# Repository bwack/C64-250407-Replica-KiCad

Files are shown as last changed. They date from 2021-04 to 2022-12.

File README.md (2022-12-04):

# The C64 250407 replica

A replica of the Commodore 64 250407 1983 mother board, and the schematics.

The replica project was started by Michael K. (Der Alte Bastler) in 2019 to learn SprintLayout and the process of reverse engineering PCB. I finished it, importet it in KiCad, imported the KU motherboard schematics and modified it to match the 250407 Reb.B schematics.

The board has been prototyped, and tested by me and Langwell Cowan.

We are not the first to reverse engineer this board, but we are the first to share the design files online I think.

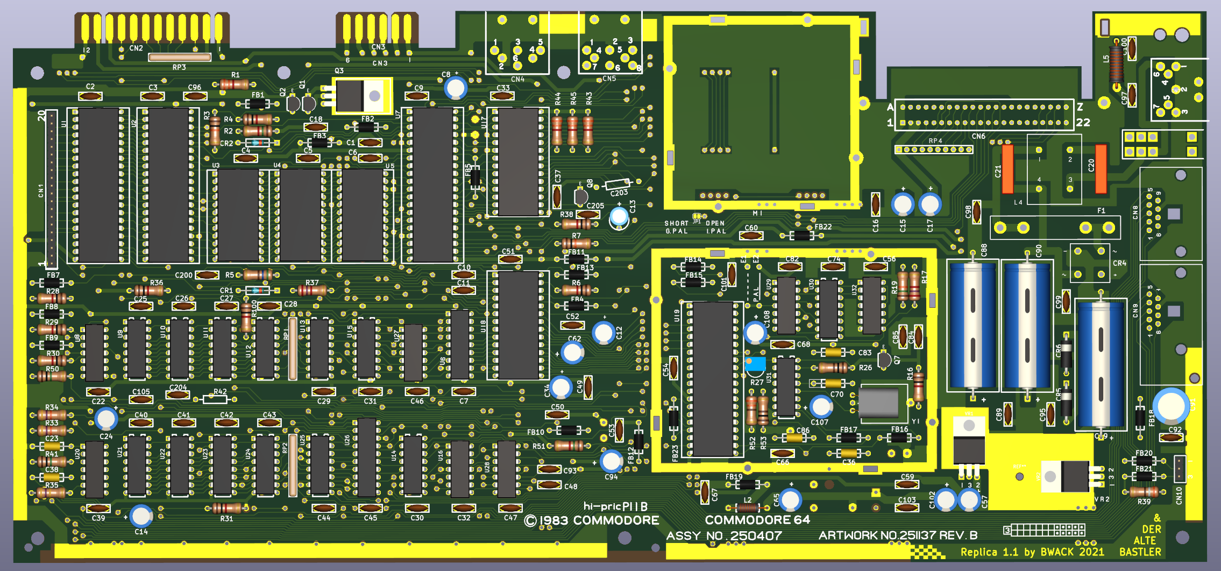
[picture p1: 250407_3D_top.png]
screenshot top

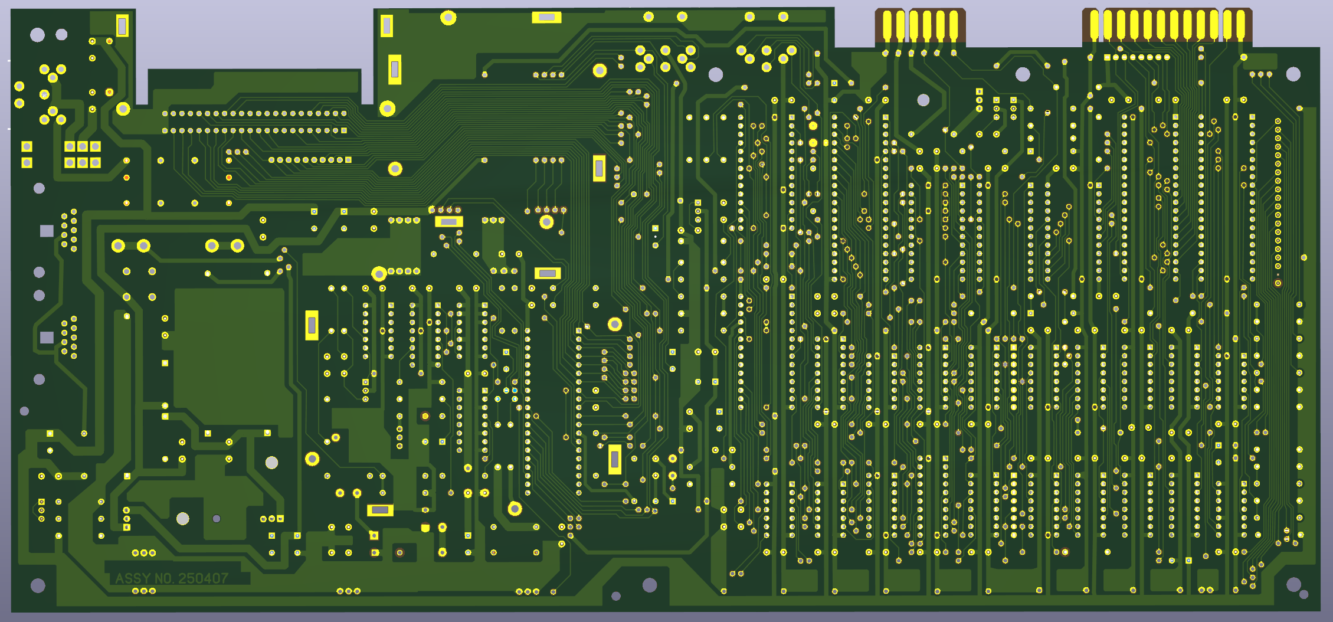
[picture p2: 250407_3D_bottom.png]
screenshot bottom


# BOM

Please see the [BOM file](250407_bom.csv).

Note that some values were left blank because they depend on the clock circuit (PAL/NTSC), and PLA model. They never made it into the schematics. You can find them in a table to the right of the schematics for 250407.
http://www.zimmers.net/anonftp/pub/cbm/schematics/computers/c64/index.html

# Interactive-BOM

[The interactive bom html page](https://htmlpreview.github.io/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) is useful for assembling the board and finding signal traces by using a web browser. Try it here. For a BOM for ordering parts see the BOM above.

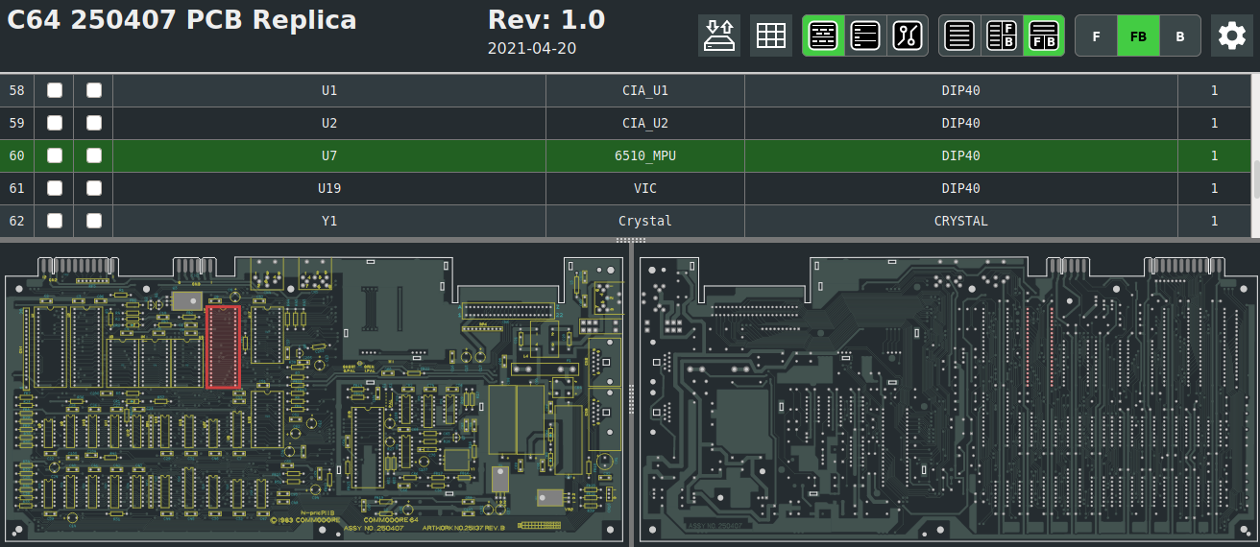
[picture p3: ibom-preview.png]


# Schematics

Download the PDF file [250407_.pdf](250407_.pdf) for a high quality schematics.
Checkout [this tweet](https://twitter.com/paulrickards/status/1371988589974847492) by Paul Rickards where he plots the KU motherboard schematics KU-14194HB :-)

# Change log
- 2022-08-18: Schematics V1.2: symbol and ERC fixes (Pull request from Gabriele Gorla/GGLABS)
- 2020-06-19: PCB and schematics V1.1: First release
- 2020-04-22: PCB and schematics V1.0: Prototype

# YouTube

Part 1-4:

IMAGE ALT TEXT HERE (https://www.youtube.com/watch?v=ox3BLlNSVFU)
IMAGE ALT TEXT HERE (https://www.youtube.com/watch?v=tBIvXRH-Mj0)
IMAGE ALT TEXT HERE (https://www.youtube.com/watch?v=Mg0gVhXbaxc)
IMAGE ALT TEXT HERE (https://www.youtube.com/watch?v=UPUVA1PZOOk)

# License and Disclaimer

Copyright Bwack 2021

This documentation describes Open Hardware and is licensed under the CERN OHL v. 1.2.

You may redistribute and modify this documentation under the terms of theCERN OHL v.1.2. (http://ohwr.org/cernohl). This documentation is distributed WITHOUT ANY EXPRESS OR IMPLIED WARRANTY, INCLUDING OF MERCHANTABILITY, SATISFACTORY QUALITY AND FITNESS FOR APARTICULAR PURPOSE. Please see the CERN OHL v.1.2 for applicable conditions.

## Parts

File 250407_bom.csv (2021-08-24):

Reference | Quantity | Value | Footprint | Mouser P/N | Reichelt P/N | Other
C96 C22 C47 C3 C2 C9 C105 C39 C46 C18 C1 C99 C98 C92 C95 C89 C59 C103 C68 C74 C67 C84 C56 C66 C82 C200 C44 C28 C43 C27 C42 C26 C41 C25 C40 C29 C4 C5 C6 C33 C31 C30 C7 C32 C45 C101 C60 C54 C53 C16 C49 C50 C52 C51 | 54 | .1 | Cap MLCC 0.1uF 50V X7R P5.08mm Radial | 80-C322C104K5R5TA or 581-SR215C104KART | X7R-5 100N
C8 C24 C57 C102 C65 C17 C94 C15 C13 C34 C62 C12 C14 C107 C108 | 15 | 10uF | Cap Alu 10uF 25V 5x5mm P2.5mm Radial | 667-ECE-A1EKS100I | M 10U 25
C11 C10 | 2 | 470pF | Cap MLCC 470pF X7R Axial | 594-A471K15X7RF5UAA | ?
C19 | 1 | 2200uF | Cap Elyt 2200uF 16V 15x30mm Axial | 594-2222-021-16222 or 594-2222-021-15222 or 598-228TTA016M | COS 105 2200/16
C203 | 1 | ? | KU-14194HB-RevB-KiCad:CAPACITOR_RADIAL_P13.97_L9.9_D3.6 | ~
C204 | 1 | ? | KU-14194HB-RevB-KiCad:CAP_P5.08mm | ~
C205 | 1 | 220pF | KU-14194HB-RevB-KiCad:CAP_P5.08mm | ~
C21 C20 | 2 | .22 | Cap Polyester Film 0.22uF 63VAC P10mm | 594-2222-368-25224 | MKS4-100 220N2
C23 | 1 | 360pF | Cap MLCC 350pF 50V C0G Axial | 594-A331J15C0GF5TAA | ?
C36 | 1 | 20pF | Cap MLCC 20pF C0G Axial | 581-SA102A200JAR | ?
C37 | 1 | 1000pF | KU-14194HB-RevB-KiCad:CAP_P5.08mm | ~
C38 | 1 | 51pF | Cap MLCC 51pF (47pF OK) X7R Axial | 581-SA102A470JAR | ?
C48 C93 | 2 | 1800pF | Cap MLCC 1800pF X7R Axial | 581-SA101C182KAR | ?
C70 | 1 | 15pF 5% | Cap MLCC 15pF 50V 5% C0G Axial/Radial Leaded | 594-A150J15C0GH5TAA | KERKO 15P
C85 | 1 | .47 | Cap MLCC 0.47uF +80/-20% X7R P5.08mm Radial | 80-C330C474K5R or 81-RCER71H474K1K1H3B | Z5U-5 470N
C86 C83 | 2 | 82pF | Cap MLCC 82pF 100V C0G Axial / Radial Disc | 80-C410C820J1G
C88 | 1 | 1000uF | Cap Elyt 1000uF 16V 20% 10x30mm Axial | 594-2222-021-15102 or 598-108TTA016M
C90 | 1 | 470uF | Cap Elyt 470uF 50V 20% 13x26mm Axial | 598-477TTA050M | COS 105 470/50
C91 | 1 | 100uF | Cap Elyt 100uF 16V 20% 6.3x11mm Radial | REA101M1CBK-0611P | FR-A 100U 16
C97 C100 | 2 | .22 | Cap MLCC 0.22uF 50V X7R P5.08mm Radial | 80-C330C224K1R | Z5U-5 220N
CN1 | 1 | KEYBOARD_20PIN_MALE | Pin Header 20 POS P2.54mm male vertical | 538-22-28-4204 | MPE 087-1-020
CN10 | 1 | LED_CONNECTOR | Pin Header 3 POS P2.54mm male vertical | 538-22-28-4033 | RND 205-00624
CN2 | 1 | USER_PORT_CON | KU-14194HB-RevB-KiCad:EDGE_CON_24P | -
CN3 | 1 | CASSETTE_PORT_CON | KU-14194HB-RevB-KiCad:EDGE_CON_12P_TAPE | -
CN4 | 1 | SERIAL_BUS_CON | KU-14194HB-RevB-KiCad:SERIAL_CON_DIN6
CN5 | 1 | AV_CONN | KU-14194HB-RevB-KiCad:AV_CON_DIN8 | -
CN6 | 1 | EXPANSION_PORT | Conn Edge Dual Female 44 POS P2.54mm |  | Digikey: H122591-ND
CN7 | 1 | POWER_CON | KU-14194HB-RevB-KiCad:POWER_CON_D7_250407
CN8 CN9 | 2 | CONTROL_PORT | Standard Connector DSUB E09P RA590 | 571-5747467-1
CR1 | 1 | IN4371 | Zener Diode 2.7V 500mW DO-35-2 | 78-TZX2V7A | ZF 2,7
CR100 CR102 CR101 CR103 | 4 | D_Small_ALT |  | ~
CR2 | 1 | IN755 | Zener Diode 7.5V 500mW DO-35-2 | 78-TZX7V5C | ZF 7,5
CR4 | 1 | BRIDGE_RECTIFIER | Bridge Rectifier 2A 600V Vf=1.05V | 627-S2VB60-5000 | KBPC604 DIO
CR5 CR6 | 2 | 1N4001 | Rectifier 1A Vr=50V | 625-1N4001-E3/54 or 625-1N4001-E3/53
E1 | 1 | JUMPER_WIRE | KU-14194HB-RevB-KiCad:JUMPER_WIRE | -
E2 | 1 | JUMPER_WIRE_DASHED | KU-14194HB-RevB-KiCad:JUMPER_WIRE | -
F1 | 2 | 1A | Fuse Clips (buy two) | 504-BK/1A1907-03-R
FB18 FB4 FB22 FB12 FB14 FB15 FB13 FB10 FB11 | 9 | FERRITE_BEAD | Ferrite Bead D3.5 L4.45mm Axial | 623-2743001112LF or 81-BL01RN1A2A2B | BEAD 8-21
FB7 FB9 FB8 FB5 FB2 FB1 FB3 FB20 FB21 FB17 FB16 FB19 FB23 | 13 | FERRITE_NARROW | Ferrite Bead D3.5 L4.45mm Axial | 623-2743001112LF or 81-BL01RN1A2A2B | BEAD 8-21
JP1 | 1 | Jumper_NC_Small | Jumper:SolderJumper-2_P1.3mm_Bridged_RoundedPad1.0x1.5mm | ~
L2 | 1 | 2.2uH | Inductor 2.2uH 5% Radial | 652-78F2R2J-RC | L-MICC 2,2µ
L4 | 1 | CHOKE | Common Mode Choke 250V 3.8mH 2.1A 150mOhms | 80-SSR10V-21038
L5 | 1 | 1.2uH | Inductor 1.5uH 10% Radial | 542-5800-4R7-RC | L-HBCC 1,5µ
M1 | 1 | MODULATOR_LONGBOARD | KU-14194HB-RevB-KiCad:MODULATOR_PORT_LONGBOARD | -
Q2 Q1 Q7 Q8 | 4 | 2SC1815 | Bipolar Transistor TO-92 Vce=60V 400mA | 2SC1815 | SC 1815
Q3 | 1 | TP29B/2SD880 | Bipolar Transistor TO-220 | 512-KSD880YTU | SD 880
R1 R43 R44 R45 | 4 | 3K3 | Resistor 3K3 0207 Axial | 594-MBB02070C3301FC1 | METALL 3,30K
R17 R37 | 2 | 2K7 | Resistor 2K7 0207 Axial | 594-MBB02070C2701FCT | METALL 2,70K
R19 | 1 | 15K | Resistor 15K 0207 Axial | 594-MBB02070C1502FC1 | METALL 15,0K
R2 R51 | 2 | 1.5K | Resistor 1K5 0207 Axial | 594-MBB02070C1501FCT | 1W 1,5K
R26 R53 | 2 | 100 | Resistor 100 0207 Axial | 594-MBB02070C1000FCT | METALL 100
R27 | 1 | 500 | Trimmer Resistor 500 Ohms Linear | 652-3306F-1-501 | BOU 3386P-1-501
R28 R30 R29 R36 R4 R16 R100 R31 R38 R6 | 10 | 1K | Resistor 1K 0207 Axial | 594-MBB02070C1001FCT | METALL 1,00K
R3 R7 | 2 | 10K | Resistor 10K 0207 Axial | 594-MBB02070C1002FCT | METALL 10,0K
R33 R34 | 2 | 47K | Resistor 47K 0207 Axial | 594-MBB02070C4702FC1 | METALL 47,0K
R35 | 1 | 470K | Resistor 470K 0207 Axial | 594-MBB02070C4703FCT | METALL 470K
R39 | 1 | 390 | Resistor 390 0207 Axial | 594-MBB02070C3900FCT | METALL 390
R41 R50 | 2 | 1M | Resistor 1M 0207 Axial | 594-MBB02070C1004FCT or 603-HHV-25JT-52-1M
R42 | 1 | ~ | KU-14194HB-RevB-KiCad:RESISTOR | - | -
R5 | 1 | 560 | Resistor 560 0207 Axial | 594-MBB02070C5600FCT | METALL 560
R52 | 1 | 330 | Resistor 330 0207 Axial | 594-MBB02070C3300FCT
RP1 RP2 | 2 | 33 | Resistor Network 33R Isolated 8 pin SIP | 652-4308R-2LF-33 or 268-33-RC
RP3 | 1 | R_ARRAY_7WAY_US | Resistor Network 3K3 Bussed 8 pin SIP | 774-77081332P
RP4 | 1 | R_ARRAY_9WAY_US | Resistor Network 3K3 Bussed 10 pin SIP | 774-770101332P
SW1 | 1 | POWER_SWITCH | KU-14194HB-RevB-KiCad:POWER_SWITCH
U1 | 1 | CIA_U1 | KU-14194HB-RevB-KiCad:DIP40 | -
U12 U24 U11 U23 U10 U22 U21 U9 | 8 | 4164-2 | KU-14194HB-RevB-KiCad:DIP16 | -
U14 | 1 | 74LS258 | QUADRUPLE 2-LINE TO 1-LINE DATA SELECTORS/MULTIPLEXERS | 595-SN74LS258BN
U15 | 1 | 74LS139 | DUAL 2-LINE TO 4-LINE DECODERS/MULTIPLEXERS | 595-SN74LS139AN
U17 | 1 | PLA_U17 | KU-14194HB-RevB-KiCad:DIP28 | -
U18 | 1 | 6581 | KU-14194HB-RevB-KiCad:DIP28 | -
U19 | 1 | VIC | KU-14194HB-RevB-KiCad:DIP40 | -
U2 | 1 | CIA_U2 | KU-14194HB-RevB-KiCad:DIP40 | -
U20 | 1 | 556 | DUAL PRECISION TIMERS | 595-NE556N
U25 U13 | 2 | 74LS257 | QUADRUPLE 2-LINE TO 1-LINE DATA SELECTORS/MULTIPLEXERS | 595-SN74LS257BN
U26 | 1 | 74LS373 | OCTAL D-TYPE TRANSPARENT LATCHES AND EDGE-TRIGGERED FLIP-FLOPS | 595-SN74LS373N
U27 | 1 | 7408 | QUADRUPLE 2-INPUT POSITIVE-AND GATES | 595-SN74LS08N
U28 U16 | 2 | 4066 | CMOS Quad Bilateral Switch | 595-CD4066BE
U29 | 1 | 74LS74 | DUAL D-TYPE POSITIVE-EDGE-TRIGGERED FLIP-FLOPS WITH PRESET AND CLEAR | 595-SN74LS74AN
U3 U4 | 2 | 2364A | KU-14194HB-RevB-KiCad:DIP24 BASIC AND KERNAL ROM | -
U30 | 1 | 74LS193 | SYNCHRONOUS 4-BIT UP/DOWN COUNTERS (DUAL CLOCK WITH CLEAR) | 595-SN74LS193N
U31 | 1 | 74LS629N | VOLTAGE-CONTROLLED OSCILLATORS | 595-SN74LS629N
U32 | 1 | MC4044 | KU-14194HB-RevB-KiCad:DIP14 | -
U5 | 1 | 2332A | KU-14194HB-RevB-KiCad:DIP24 CHAR ROM | -
U6 | 1 | 2114 | KU-14194HB-RevB-KiCad:DIP18 COLOR RAM | -
U7 | 1 | 6510_MPU | KU-14194HB-RevB-KiCad:DIP40 | -
U8 | 1 | 7406N | HEX INVERTER BUFFERS/DRIVERSWITH OPEN-COLLECTOR HIGH-VOLTAGE OUTPUTS | 595-SN7406N
VR1 | 1 | 7812 | Linear Voltage Regulators 12V 1A Positive | 863-MC7812CTG
VR2 | 1 | 7805 | Linear Voltage Regulators 5V 1A Positive | 863-MC7805CTG
Y1 | 1 | Crystal | Crystals HC49/U | 815-AB-17.734475-B4
Other:
 | Quantity |  | Description | mouser
 | 4 |  | Socket PDIP 40P P2.54mm W15.24mm DUAL WIPE | 517-4840-6000-CP
 | 2 |  | Socket PDIP 28P P2.54mm W15.24mm DUAL WIPE | 517-4828-6000-CP
 | 3 |  | Socket PDIP 24P P2.54mm W15.24mm DUAL WIPE | 517-4824-6000-CP
 | 1 |  | Socket PDIP 20P P2.54mm W7.62mm DUAL WIPE | 517-4820-3000-CP
 | 1 |  | Socket PDIP 18P P2.54mm W7.62mm DUAL WIPE | 517-4818-3000-CP
 | 14 |  | Socket PDIP 16P P2.54mm W7.62mm DUAL WIPE | 517-4816-3000-CP
 | 7 |  | Socket PDIP 14P P2.54mm W7.62mm DUAL WIPE | 517-4814-3000-CP

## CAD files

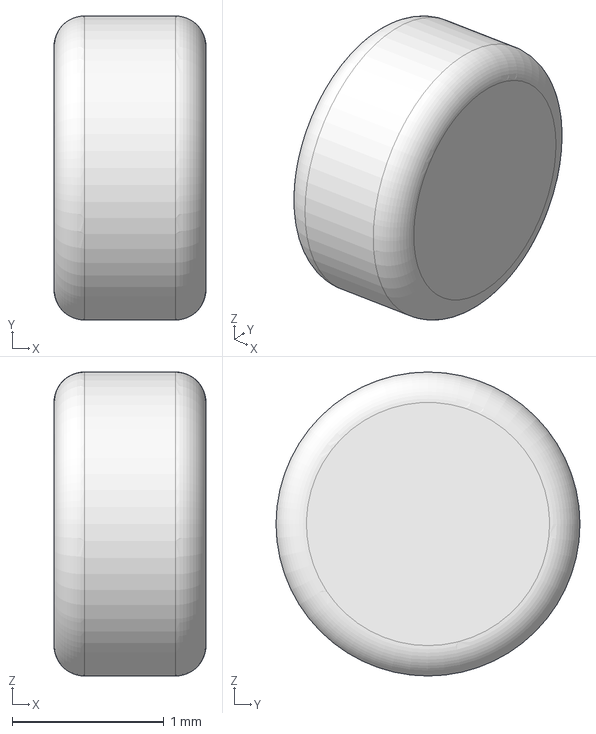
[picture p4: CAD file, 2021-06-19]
3D-models/unitary_ring.fcstd
1.00 x 2.00 x 2.00 mm

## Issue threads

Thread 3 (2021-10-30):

Q7 on the interactive BOM should be c945

TheSupremeMonkey, 2021-10-30:
I love the project and have been watching it on YouTube just waiting for the open release. Just finished my first board and I only ran into one issue. The interactive BOM lists a C1815 for the Q7 transistor for the video circuit. When I used one I got garbage video output.  I could just barely tell that basic was up but the static was so bad it was unusable. I have a bunch of 250407 boards and when I checked my stock boards they all had a C945 with the higher maximum frequency. When I swapped a C945 in for the C1815 everything worked great and the picture was perfect.

TheSupremeMonkey, 2021-10-31:
The more I think about it and look at the schematics I'm starting to think maybe I just had a bad transistor. When I get a chance I may test a few different transistors to see if it was just a bad component.

TheSupremeMonkey, 2021-10-31:
Looks like it was just a bad transistor. Sorry for the false alarm.

Closed 2021-10-31.

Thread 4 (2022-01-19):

Should R31 be 1K or 180R ?

DusteDdk, 2022-01-19:
Thank you for the awesome interactive BOM, it's an great tool!
In the IBOM R31 is listed as 1K but I think it should be 180 Ohm,
Is this a difference between NTSC and PAL ?

bwack, 2022-02-08:
Hi. I confirmed that R31 is 1K in the Schematics PDF and ibom.
I remember this being 180 in the original schematics for the longboards.
1. I've seen 1K used on the PCB boards
2. 180 Ohms would stress the 7406, wouldn't have enough output drive to drag the voltage down.

DusteDdk, 2022-02-09:
Yes now I understand, it's simply a pullup, 180 ohm worked fine on my byard, but I it's a balance between noise and power usage, I changed mine to 1k as well, it still seems to work just fine, thanks for saving our 7406's ;)

Closed 2022-02-09.

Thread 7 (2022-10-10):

Testing the rails

SR-dude, 2022-10-10:
I think I’ll take the plunge.  Is the breadboard sold at pcbway the better one?

More seriously, I’ve seen some videos where people just put the board together without testing as they go. No checking their work. I don’t want to take that approach. What I want to do is use a bench power supply and test the traces on the board, even before installing the 12 & 5 V regulators.  Where on your board where the voltages should be tapped?

bwack, 2022-10-11:
Check the schematic and the interactive bom. It's all there.

bwack, 2022-10-11:
I don't understand the breadboard question.

bwack, 2022-10-11:
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
You'll find the interactive BOM in the readme page.

SR-dude, 2022-10-11:
Thanks.  I’ll get the the board from pcbway sponsored by you.

bwack, 2022-10-11:
Only the video was sponsored , but cool that you get this board anyway 🙂

Closed 2022-10-11.

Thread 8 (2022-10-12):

Beveling?

SR-dude, 2022-10-12:
When placing the order for your shared project at pcbway, I was asked a question.  “You(me) chose “beveling” online but noted “not beveling “.  I checked and the default choice is “Yes at 30 degrees”. I don’t know how beveling could have been turned off. Did the gerbers do it?. What do you recommend?

bwack, 2022-10-12:
Bevelling, as in making the pcb edge connectors chamfered at an angle is not possible to choose in gerber i think, therefore they ask.

Though they will probably get back to you and say that they can't do it because the pcb edge connectors are not far enough out on the edge. They told me otherwise the whole upper edge of the pcb would be bevelled. I guess they don't have a tool that can do only the connector, just the full edge if you know what mean.

SR-dude, 2022-10-12:
I suppose I should leave beveling off then.

Closed 2022-12-02.

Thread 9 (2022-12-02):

Orientation of the L4 choke

SR-dude, 2022-12-02:
I have a indented corner and on the opposite corner it reads "BL".  There are two orientations to fit this in L4. The indent is either pin 2 or pin 4. Do you know which?

bwack, 2022-12-04:
I don't know your part, and BL I don't know. So you are asking if it is possible to mount is backwards ? It would work, as long as you don't mount it "side ways", then it would short the power supply.
Looking at the common mode chokes, the look very symmetrical though, so I wouldn't worry about the orientation other than having it pass current rather than shorting it. If it's an open design, you can see where the wires go, if not you can use a multimeter to find what pins are joined (measure a low resistance). I hope this helps.

SR-dude, 2022-12-04:
I got it from a retro shop that  sells a c64 parts kit.  I think its a Kemet  SU10VD-10010. In any case, looking at it, it looks like that it is symmetrical. It's not square. So, there is only two ways to fit. Either will do.

Closed 2022-12-04.

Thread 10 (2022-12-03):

C203

SR-dude, 2022-12-03:
What do you suggest I do about C203? It has no value and footprint in the BOM:
KU-14194HB-RevB-KiCad:CAPACITOR_RADIAL_P13.97_L9.9_D3.6

The interactive BOM calls it a 82pF Radial Capacitor. But, it doesn't appear to be
 connected. You videos on youtube just skip it.

It might help me better to understand what "P13.97_L9.9_D3.6" means.

bwack, 2022-12-04:
If you look up the original schematics for the 250407, C203 is mentioned in a table to the right.
http://www.zimmers.net/anonftp/pub/cbm/schematics/computers/c64/251138-1of2-right.gif

The name of the footprint is just an identifier for the footprint, not the part. P L D stands for Pitch length diameter. I think, it's been a while.

SR-dude, 2022-12-04:
Okay, from what I read about c203, it is never populated.

Closed 2022-12-04.

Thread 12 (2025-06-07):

250407 E1/E2/E3 PAL/NTSC corrections

fredsa, 2025-06-07:
Here's my board:
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

Here are two places where corrections are needed:

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

bwack, 2025-06-07:
Thanks, Fred! I see an error on the silkscreen. What is the second error?

bwack, 2025-06-09:
Done. Thanks !

Closed 2025-06-09.

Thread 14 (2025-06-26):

Bar above inverted signals renders poorly in PDF

fredsa, 2025-06-26:
In a recent update (thank you for the https://github.com/bwack/C64-250407-Replica-KiCad/pull/13 fixes!), the rendering of the PDF changed, making it more difficult to clearly make out the bar above inverted signals.

Compare:

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

- Does KiCAD 9.0.1 maybe render differently?
- Are there KiCAD or 'print to PDF' settings that could be changed to make the output better?

bwack, 2025-06-29:
I checked. Yes it renders differently, and no there are no export functions for this. Unfortunately.

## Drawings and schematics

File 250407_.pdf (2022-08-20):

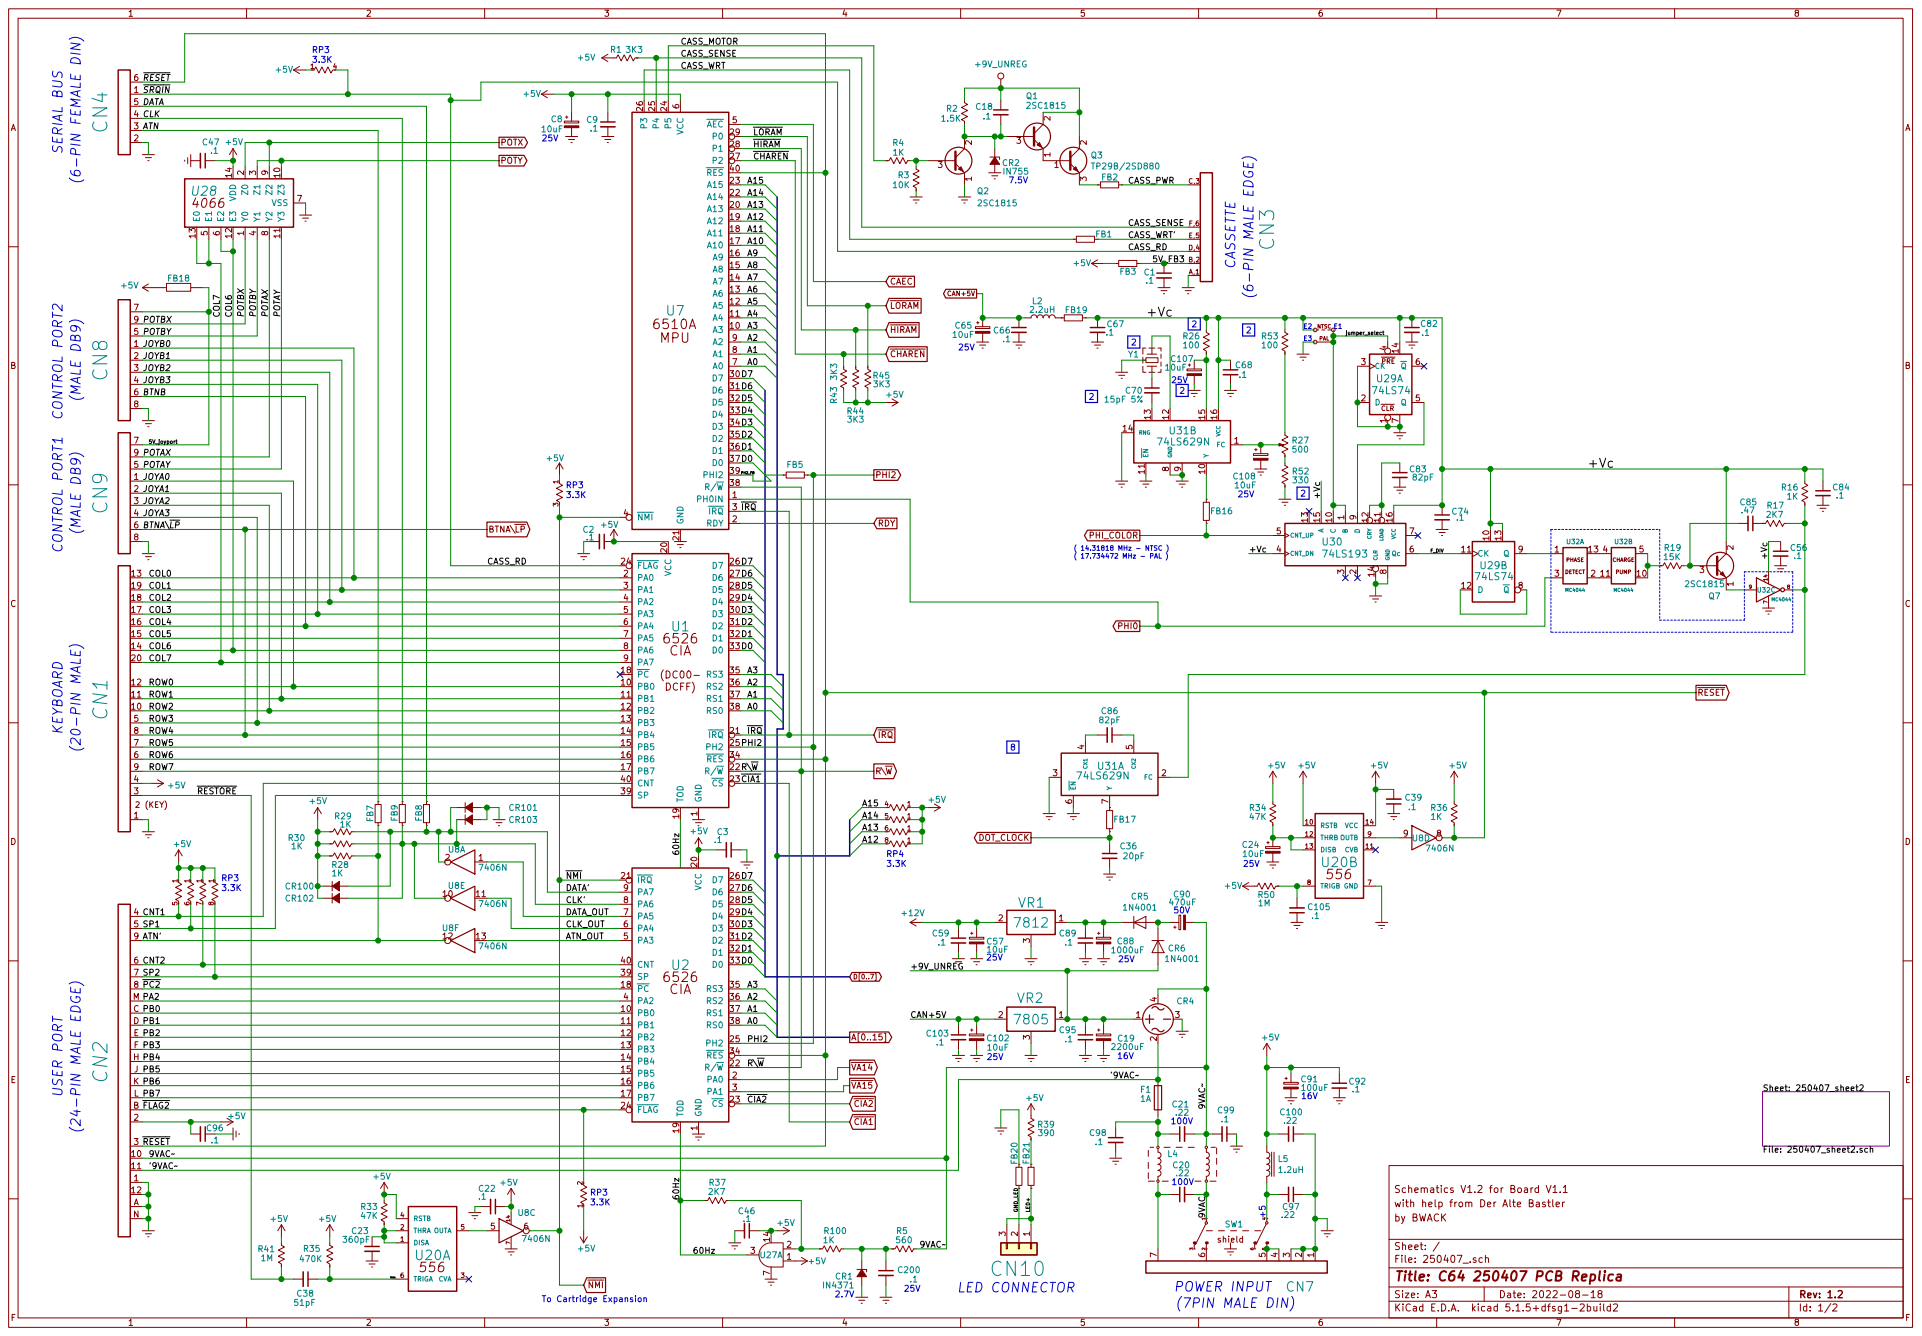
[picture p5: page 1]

To Cartridge Expansion (MALE DB9) CONTROL PORT2

3 JOYB2

2 JOYA1
4 JOYA3

IRQ

19
18
17
16
15

(7PIN MALE DIN) KEYBOARD (20-PIN MALE)

12
11
10
ROW7 | R\W
4 | CIA1

7 SP2

'9VAC

11 '9VAC

File: 250407_.sch Sheet: / by BWACK

Id: 1/2 Title: C64 250407 PCB Replica

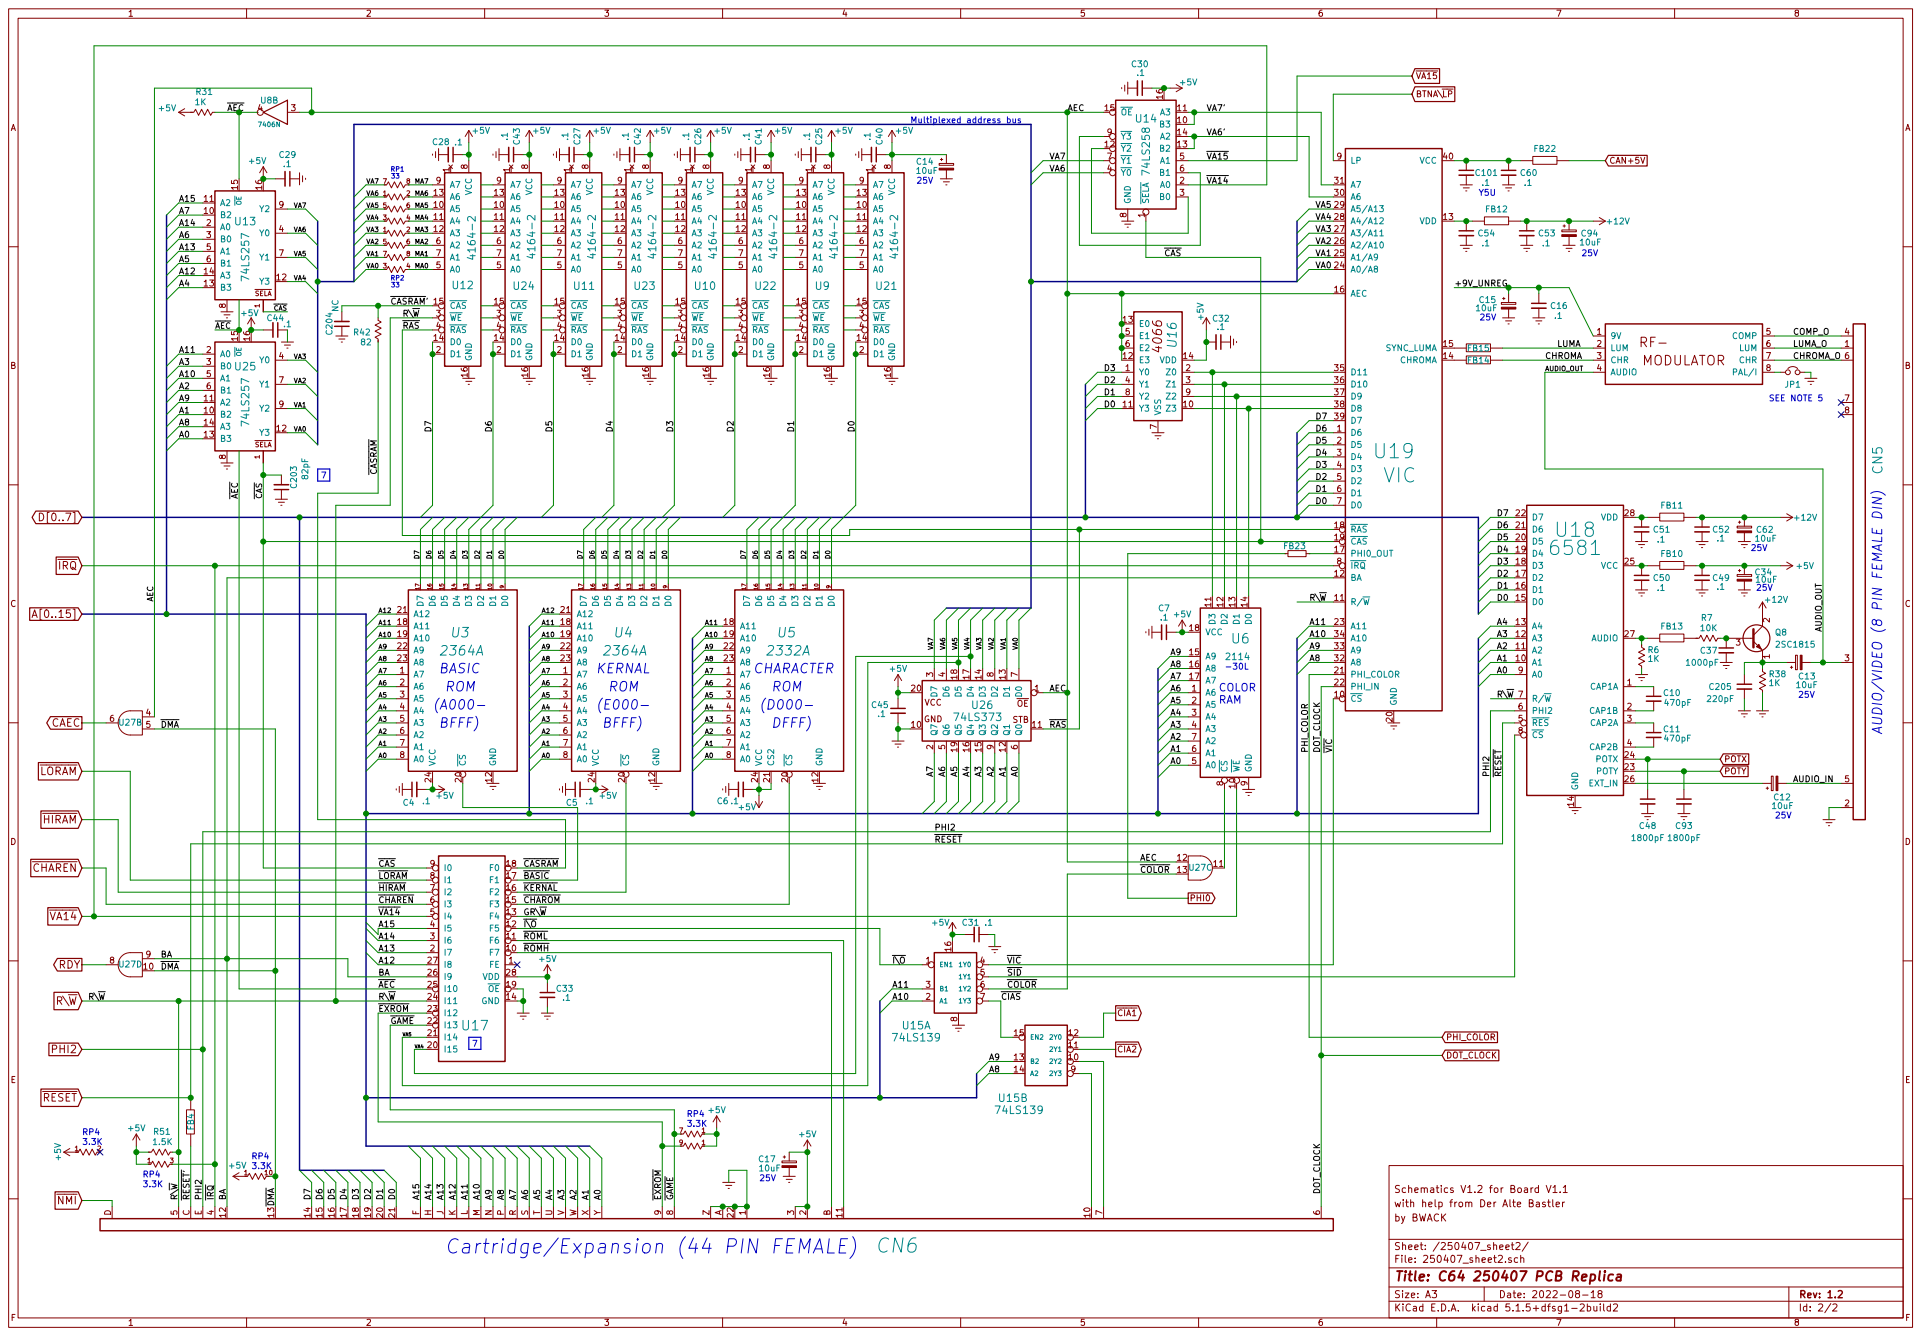
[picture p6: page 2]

1 A5 10 A4 11 A3 12 A6 13 D0 14 CAS 15 GND 16 D1 2 WE 3 RAS 4 A0 5 A2 6 A1 7 VCC

with help from Der Alte Bastler Schematics V1.2 for Board V1.1

Sheet: /250407_sheet2/
File: 250407_sheet2.sch
Id: 2/2 Title: C64 250407 PCB Replica

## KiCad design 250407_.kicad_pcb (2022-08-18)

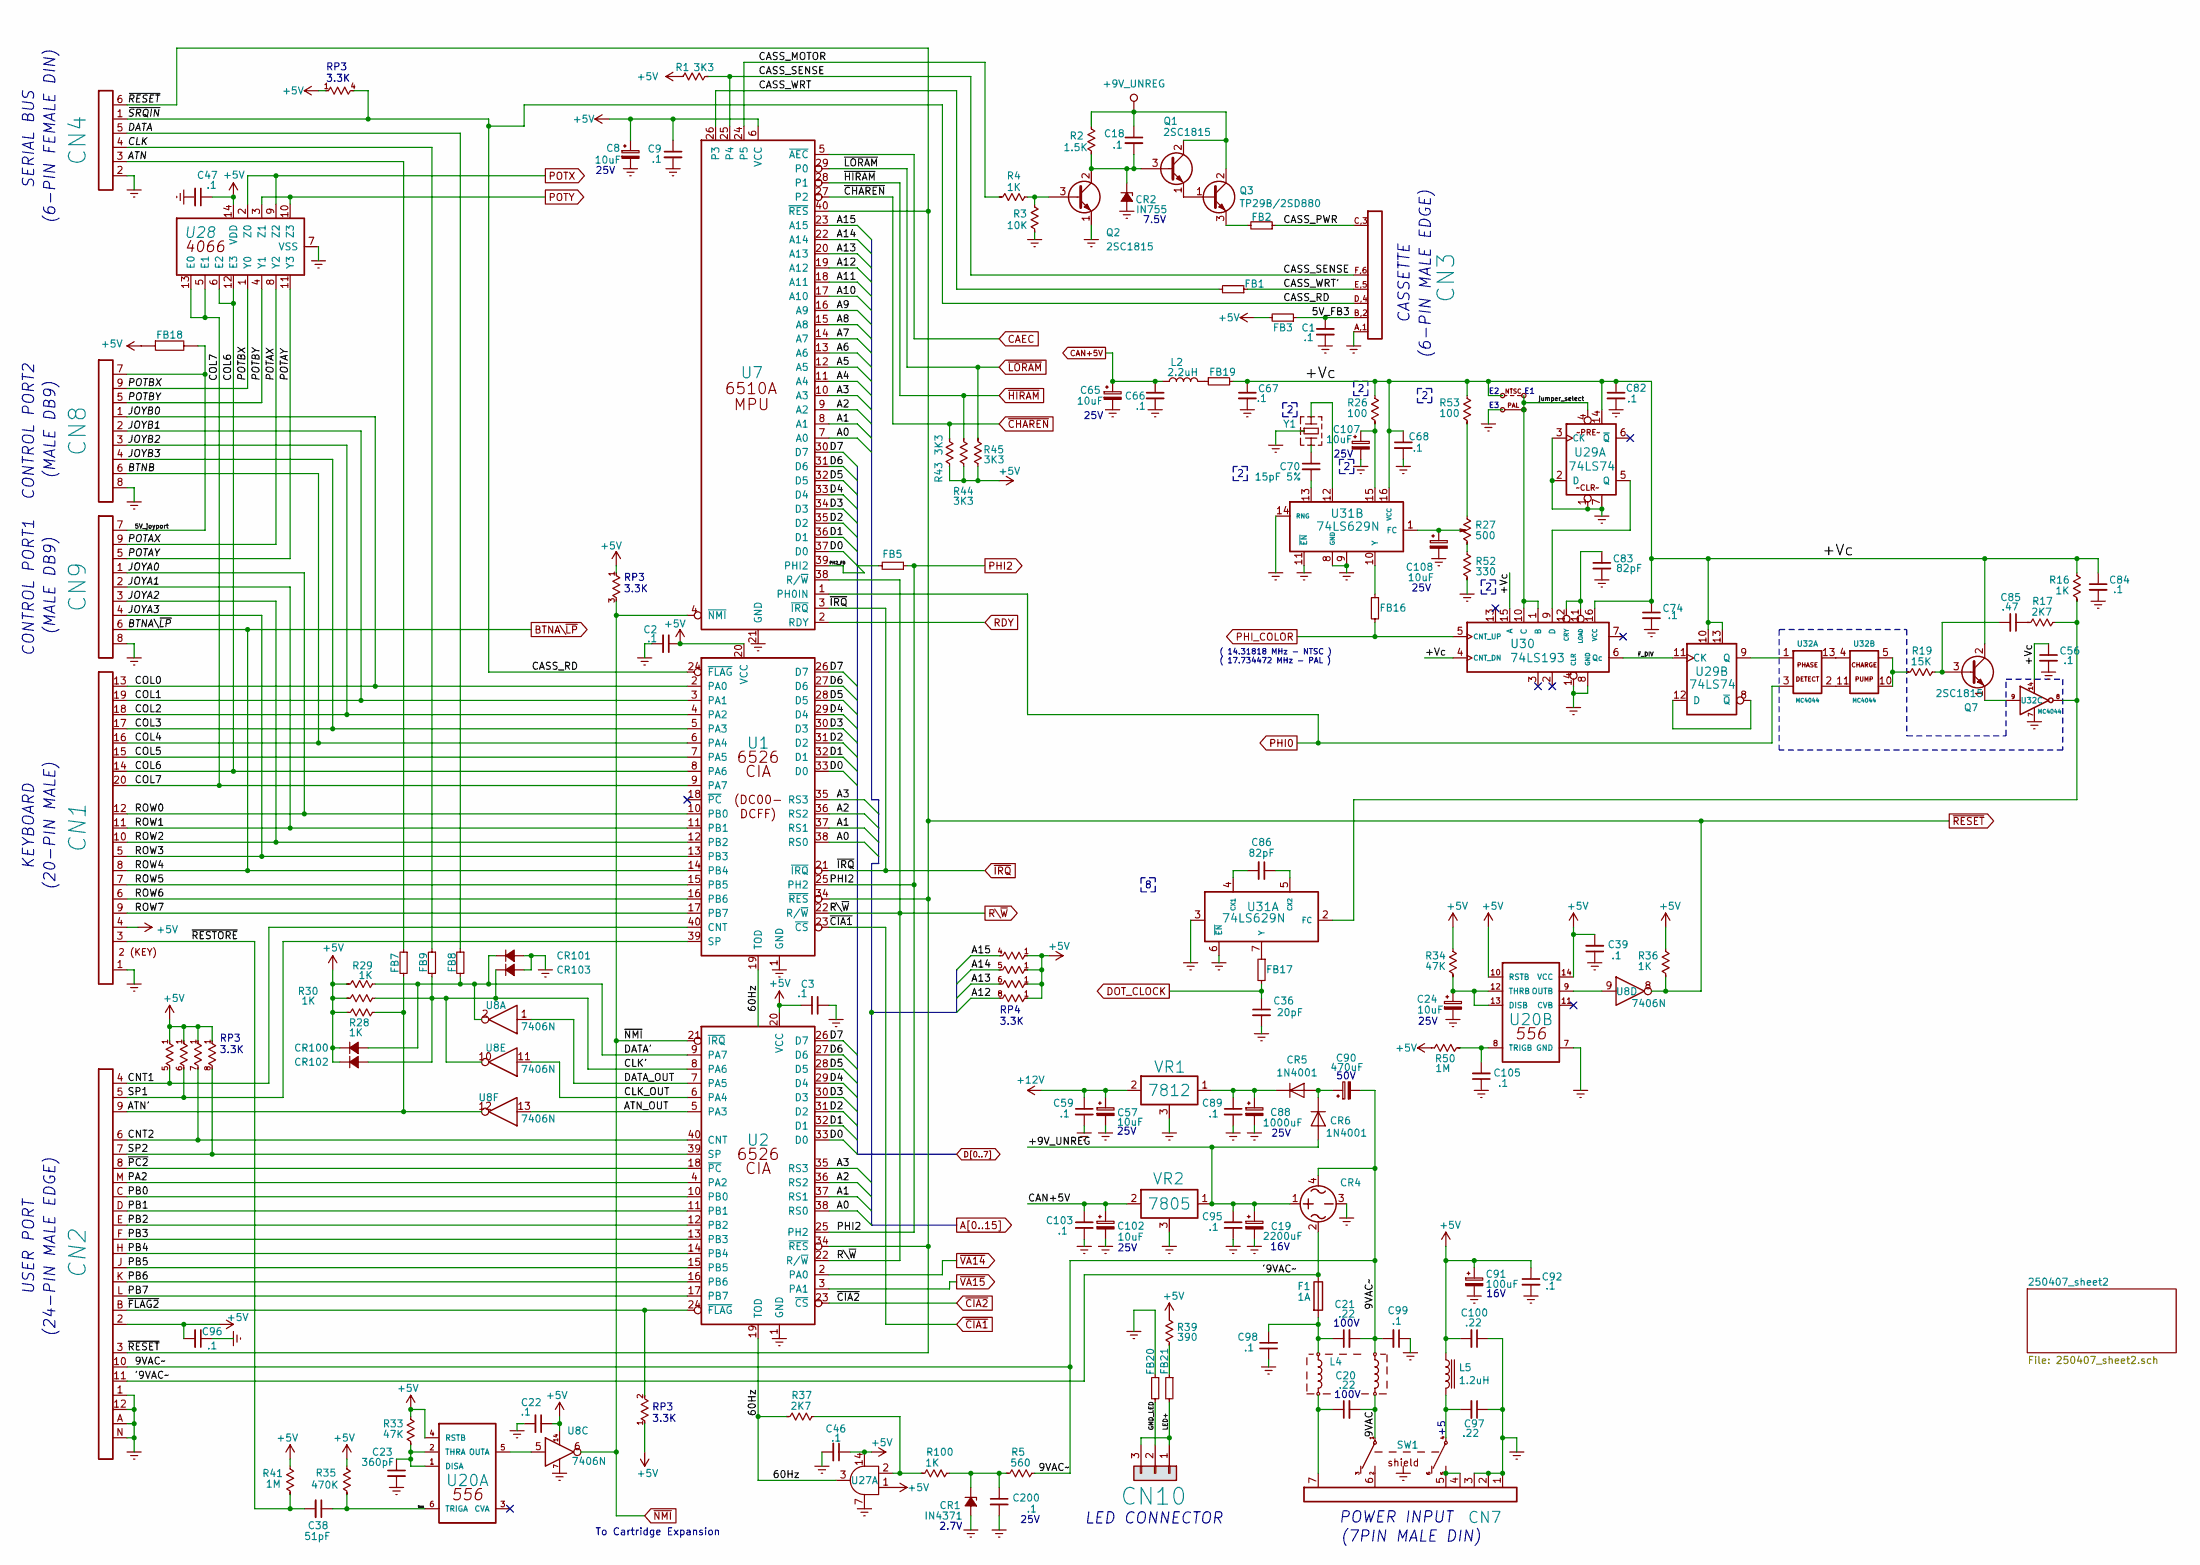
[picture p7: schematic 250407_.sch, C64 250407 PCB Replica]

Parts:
C1, C2, C3, C9, C18, C22, C39, C46, C47, C56, C59, C66, C67, C68, C74, C82, C84, C89, C92, C95, C96, C98, C99, C103, C105, C200: .1; CAP_P5.08mm
C8, C24, C57, C65, C102, C107, C108: 10uF; CAP_ELYT_RADIAL_P5.08mm_SMALL_RING
C19: 2200uF; LARGE_ELECTROLYTIC_AXIAL_TH
C20, C21: .22; CAP_POLY_100V_TH_P5.08_and_P12.07mm
C23: 360pF; CAP_AXIAL_P12.7mm
C36: 20pF; RESISTOR
C38: 51pF; CAP_AXIAL_P12.7mm
C70: 15pF 5%; RESISTOR
C83, C86: 82pF; RESISTOR
C85: .47; CAP_P5.08mm
C88: 1000uF; LARGE_ELECTROLYTIC_AXIAL_TH
C90: 470uF; LARGE_ELECTROLYTIC_AXIAL_TH
C91: 100uF; CAP_ELYT_RADIAL_P5.08mm
C97, C100: .22; CAP_P5.08mm
CN1: KEYBOARD_20PIN_MALE; KEYBOARD_CON
CN2: USER_PORT_CON; EDGE_CON_24P
CN3: CASSETTE_PORT_CON; EDGE_CON_12P_TAPE
CN4: SERIAL_BUS_CON; SERIAL_CON_DIN6
CN7: POWER_CON; POWER_CON_D7_250407
CN8, CN9: CONTROL_PORT; JOYPORT_DB9
CN10: LED_CONNECTOR; LED_CON
CR1: IN4371; ZENER_12.7mm
CR2: IN755; ZENER_12.7mm
CR4: BRIDGE_RECTIFIER
CR5, CR6: 1N4001; RECTIFIER_TH_P12.7mm
CR100, CR101, CR102, CR103: D_Small_ALT
E1: JUMPER_WIRE
E2: JUMPER_WIRE_DASHED; JUMPER_WIRE
F1: 1A; FUSE
FB1, FB2, FB3, FB5, FB7, FB8, FB9, FB16, FB17, FB18, FB19, FB20, FB21: FERRITE_BEAD; FERRITE_BEAD_TH_P12.7mm
L2: 2.2uH; RESISTOR
L4: CHOKE
L5: 1.2uH; INDUCTOR_P15.24mm
Q1, Q2, Q7: 2SC1815; Q_NPN_ECB
Q3: TP29B/2SD880; TO-220-3_Horizontal_TabDown_250407
R1, R43, R44, R45: 3K3; RESISTOR
R2: 1.5K; RESISTOR
R3: 10K; RESISTOR
R4, R16, R28, R29, R30, R36, R100: 1K; RESISTOR
R5: 560; RESISTOR
R17, R37: 2K7; RESISTOR
R19: 15K; RESISTOR
R26, R53: 100; RESISTOR
R27: 500; POTMETER
R33, R34: 47K; RESISTOR
R35: 470K; RESISTOR
R39: 390; RESISTOR
R41, R50: 1M; RESISTOR
R52: 330; RESISTOR
RP3: 3K3 Bussed; RP_ARRAY_7WAY
RP4: 3K3 Bussed; RP_ARRAY_9WAY
SW1: POWER_SWITCH
U1: CIA_U1; DIP40
U2: CIA_U2; DIP40
U7: 6510_MPU; DIP40
U8: 7406N; DIP14
U20: 556; DIP14
U27: 7408_U27; DIP14
U28: 4066_U28; DIP14
U29: 74LS74; DIP14
U30: 74LS193; DIP16
U31: 74LS629N; DIP16
U32: MC4044; DIP14
VR1: 7812; VREG_TO-220-3_Horizontal_TabDown
VR2: 7805; VREG_TO-220-3_Horizontal_TabDown
Y1: Crystal; CRYSTAL

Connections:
+5V: C2.1, C3.2, C8.1, C9.1, C22.1, C39.2, C46.1, C47.1, C91.1, C92.1, C96.2, C100.2, CN1.4, CN2.2, CR100.1 (K), CR102.1 (K), FB3.2, FB18.1, L5.1, R1.1, R28.2, R29.2, R30.2, R33.1, R34.1, R35.1, R36.1, R39.1, R41.1, R43.1, R44.1, R45.1, R50.1, RP3.1, RP4.1, U1.20 (VCC), U2.20 (VCC), U7.6 (VCC), U8.14, U20.4 (RSTB), U20.10 (RSTB), U20.14 (VCC), U27.1, U27.14, U28.14 (VDD); also elsewhere on the board
+9V_UNREG: C18.1, C19.1, C95.1, CR4.1, CR6.2 (A), Q1.2 (C), Q3.2 (C), R2.1, VR2.1; also elsewhere on the board
+12V: C57.1, C59.1, VR1.2; also elsewhere on the board
/5V_FB3: C1.1, CN3.B,2, FB3.1
/5V_joyport: CN8.7, CN9.7, FB18.2
/9VAC: C20.2, L4.3, SW1.1
/9VAC~~: C21.2, C90.2, C99.2, CN2.10, CR4.4, L4.4, R5.1
/60Hz: R37.2, U1.19 (TOD), U2.19 (TOD), U27.3
/'9VAC~~: CN2.11, CR4.2, F1.1
/+Vc: C56.1, C67.1, C68.1, C74.1, C82.1, C84.1, E2.1, FB19.2, Q7.2 (C), R16.1, R26.1, R53.1, U29.10, U29.13, U29.14, U30.4 (CNT_DN), U30.15 (A), U30.16 (VCC), U31.16 (VCC), U32.14
/ATN: CN4.3, FB7.1
/ATN': CN2.9, FB7.2, R28.1, U8.12
/ATN_OUT: U2.5 (PA3), U8.13
/BTNB: CN1.16, CN8.6, U1.6 (PA4)
/CASS_MOTOR: R4.2, U7.24 (P5)
/CASS_PWR: CN3.C,3, FB2.1
/CASS_RD: CN3.D,4, CN4.1, RP3.4, U1.24 (~FLAG~)
/CASS_SENSE: CN3.F,6, R1.2, U7.25 (P4)
/CASS_WRT: FB1.2, U7.26 (P3)
/CASS_WRT': CN3.E,5, FB1.1
/CLK: CN4.4, FB9.1
/CLK': CR102.2 (A), CR103.1 (K), FB9.2, R30.1, U2.8 (PA6), U8.10
/CLK_OUT: U2.6 (PA4), U8.11
/CNT1: CN2.4, RP3.5, U1.40 (CNT)
/CNT2: CN2.6, RP3.7, U2.40 (CNT)
/COL0: CN1.13, CN8.1, U1.2 (PA0)
/COL1: CN1.19, CN8.2, U1.3 (PA1)
/COL2: CN1.18, CN8.3, U1.4 (PA2)
/COL3: CN1.17, CN8.4, U1.5 (PA3)
/COL5: CN1.15, U1.7 (PA5)
/COL6: CN1.14, U1.8 (PA6), U28.6 (E2), U28.12 (E3)
/COL7: CN1.20, U1.9 (PA7), U28.5 (E1), U28.13 (E0)
/DATA: CN4.5, FB8.1
/DATA': CR100.2 (A), CR101.1 (K), FB8.2, R29.1, U2.9 (PA7), U8.2
/DATA_OUT: U2.7 (PA5), U8.1
/F_DIV: U29.11 (CK), U30.6 (Qc)
/GND_LED: CN10.2, FB20.2
/JOYA0: CN1.12, CN9.1, U1.10 (PB0)
/JOYA1: CN1.11, CN9.2, U1.11 (PB1)
/JOYA2: CN1.10, CN9.3, U1.12 (PB2)
/JOYA3: CN1.5, CN9.4, U1.13 (PB3)
/LED+: CN10.1, CN10.3, FB21.2
/PA2: CN2.M, U2.4 (PA2)
/PB0: CN2.C, U2.10 (PB0)
/PB1: CN2.D, U2.11 (PB1)
/PB2: CN2.E, U2.12 (PB2)
/PB3: CN2.F, U2.13 (PB3)
/PB4: CN2.H, U2.14 (PB4)
/PB5: CN2.J, U2.15 (PB5)
/PB6: CN2.K, U2.16 (PB6)
/PB7: CN2.L, U2.17 (PB7)
/PH2_FB: FB5.2, U7.39 (PHI2)
/POTAX: CN9.9, U28.8 (Y2)
/POTAY: CN9.5, U28.11 (Y3)
/POTBX: CN8.9, U28.1 (Y0)
/POTBY: CN8.5, U28.4 (Y1)
/ROW5: CN1.7, U1.15 (PB5)
/ROW6: CN1.6, U1.16 (PB6)
/ROW7: CN1.9, U1.17 (PB7)
/SP1: CN2.5, RP3.6, U1.39 (SP)
/SP2: CN2.7, RP3.8, U2.39 (SP)
/TRIGA: C38.1, R35.2, U20.6 (TRIGA)
/jumper_select: E1.2, E2.2, U29.4, U30.1 (B), U30.10 (C)
/~FLAG2~: CN2.B, RP3.2, U2.24 (~FLAG~)
/~PC2~: CN2.8, U2.18 (~PC~)
/~RESTORE~: C38.2, CN1.3, R41.2
A0: U1.38 (RS0), U2.38 (RS0), U7.7 (A0); also elsewhere on the board
A1: U1.37 (RS1), U2.37 (RS1), U7.8 (A1); also elsewhere on the board
A2: U1.36 (RS2), U2.36 (RS2), U7.9 (A2); also elsewhere on the board
A3: U1.35 (RS3), U2.35 (RS3), U7.10 (A3); also elsewhere on the board
A4: U7.11 (A4); also elsewhere on the board
A5: U7.12 (A5); also elsewhere on the board
A6: U7.13 (A6); also elsewhere on the board
A7: U7.14 (A7); also elsewhere on the board
A8: U7.15 (A8); also elsewhere on the board
A9: U7.16 (A9); also elsewhere on the board
A10: U7.17 (A10); also elsewhere on the board
A11: U7.18 (A11); also elsewhere on the board
A12: RP4.8, U7.19 (A12); also elsewhere on the board
A13: RP4.6, U7.20 (A13); also elsewhere on the board
A14: RP4.5, U7.22 (A14); also elsewhere on the board
A15: RP4.4, U7.23 (A15); also elsewhere on the board
BTNA\~LP~: CN1.8, CN9.6, U1.14 (PB4); also elsewhere on the board
CAEC: U7.5 (~AEC~); also elsewhere on the board
CAN+5V: C65.1, C66.1, C102.1, C103.1, L2.1, VR2.2; also elsewhere on the board
D0: U1.33 (D0), U2.33 (D0), U7.37 (D0); also elsewhere on the board
D1: U1.32 (D1), U2.32 (D1), U7.36 (D1); also elsewhere on the board
D2: U1.31 (D2), U2.31 (D2), U7.35 (D2); also elsewhere on the board
D3: U1.30 (D3), U2.30 (D3), U7.34 (D3); also elsewhere on the board
D4: U1.29 (D4), U2.29 (D4), U7.33 (D4); also elsewhere on the board
D5: U1.28 (D5), U2.28 (D5), U7.32 (D5); also elsewhere on the board
D6: U1.27 (D6), U2.27 (D6), U7.31 (D6); also elsewhere on the board
D7: U1.26 (D7), U2.26 (D7), U7.30 (D7); also elsewhere on the board
DOT_CLOCK: C36.1, FB17.2; also elsewhere on the board
Earth: C1.2, C2.2, C3.1, C8.2, C9.2, C19.2, C22.2, C23.2, C24.2, C36.2, C39.1, C46.2, C47.2, C56.2, C57.2, C59.2, C65.2, C66.2, C67.2, C68.2, C74.2, C82.2, C83.2, C84.2, C88.2, C89.2, C91.2, C92.2, C95.2, C96.1, C97.1, C98.2, C99.1, C100.1, C102.2, C103.2, C105.1, C107.2, C108.2, C200.2, CN1.1, CN2.1, CN2.12, CN2.A, CN2.N, CN3.A,1, CN4.2, CN7.1, CN7.2, CN7.3, CN8.8, CN9.8, CR1.2 (A), CR2.2 (A), CR4.3, CR101.2 (A), CR103.2 (A), E1.1, FB20.1, Q2.1 (E), R3.2, R52.2, SW1.~ (pe), U1.1 (GND), U2.1 (GND), U7.21 (GND), U8.7, U20.7 (GND), U27.7, U28.7 (VSS), U29.1, U29.2 (D), U29.3 (CK), U29.7, U30.8 (GND), U30.14 (CLR), U31.3, U31.6 (~EN~), U31.8 (GND), U31.9, U31.11 (~EN~), U31.14 (RNG), U32.7, VR1.3, VR2.3, Y1.3; also elsewhere on the board
unnamed: C18.2, CR2.1 (K), Q1.3 (B), Q2.2 (C), R2.2
unnamed: C20.1, CN7.7, L4.2
unnamed: C21.1, C98.1, F1.2, L4.1
unnamed: C23.1, R33.2, U20.1 (DISA), U20.2 (THRA)
unnamed: C24.1, R34.2, U20.12 (THRB), U20.13 (DISB)
unnamed: C70.1, Y1.2
unnamed: C70.2, U31.13
unnamed: C83.1, U30.11 (LOAD), U30.12 (CRY)
unnamed: C85.1, R17.2
unnamed: C85.2, Q7.3 (B), R19.1
unnamed: C86.1, U31.5 (CX2)
unnamed: C86.2, U31.4 (CX1)
unnamed: C88.1, C89.1, CR5.1 (K), VR1.1
unnamed: C90.1, CR5.2 (A), CR6.1 (K)
unnamed: C97.2, L5.2, SW1.4
unnamed: C105.2, R50.2, U20.8 (TRIGB)
unnamed: C107.1, R26.2, U31.15
unnamed: C108.1, R27.3, U31.1 (FC)
unnamed: C200.1, CR1.1 (K), R5.2, R100.1
unnamed: CN7.4, CN7.5, SW1.5
unnamed: CN7.6, SW1.2
unnamed: FB2.2, Q3.3 (E)
unnamed: FB16.1, U31.10 (Y)
unnamed: FB17.1, U31.7 (Y)
unnamed: FB19.1, L2.2
unnamed: FB21.1, R39.2
unnamed: Q1.1 (E), Q3.1 (B)
unnamed: Q2.3 (B), R3.1, R4.1
unnamed: Q7.1 (E), U32.9
unnamed: R16.2, R17.1, U31.2 (FC), U32.8
unnamed: R19.2, U32.5, U32.10
unnamed: R27.1, R53.2
unnamed: R27.2, R52.1
unnamed: R37.1, R100.2, U27.2
unnamed: U8.5, U20.5 (OUTA)
unnamed: U8.9, U20.9 (OUTB)
unnamed: U29.5 (Q), U30.9 (D)
unnamed: U29.9 (Q), U32.1
unnamed: U29.8 (~Q~), U29.12 (D)
unnamed: U31.12, Y1.1
unnamed: U32.2, U32.11
unnamed: U32.4, U32.13
PHI0: U7.1 (PH0IN), U32.3; also elsewhere on the board
PHI2: FB5.1, U1.25 (PH2), U2.25 (PH2); also elsewhere on the board
PHI_COLOR: FB16.2, U30.5 (CNT_UP); also elsewhere on the board
POTX: U28.2 (Z0), U28.9 (Z2); also elsewhere on the board
POTY: U28.3 (Z1), U28.10 (Z3); also elsewhere on the board
RDY: U7.2 (RDY); also elsewhere on the board
R\~W~: U1.22 (R/~W~), U2.22 (R/~W~), U7.38 (R/~W~); also elsewhere on the board
~CHAREN~: R43.2, U7.27 (P2); also elsewhere on the board
~CIA1~: U1.23 (~CS~); also elsewhere on the board
~CIA2~: U2.23 (~CS~); also elsewhere on the board
~HIRAM~: R44.2, U7.28 (P1); also elsewhere on the board
~IRQ~: U1.21 (~IRQ~), U7.3 (~IRQ~); also elsewhere on the board
~LORAM~: R45.2, U7.29 (P0); also elsewhere on the board
~NMI~: RP3.3, U2.21 (~IRQ~), U7.4 (~NMI~), U8.6; also elsewhere on the board
~RESET~: CN2.3, CN4.6, R36.2, U1.34 (~RES~), U2.34 (~RES~), U7.40 (~RES~), U8.8; also elsewhere on the board
~VA14~: U2.2 (PA0); also elsewhere on the board
~VA15~: U2.3 (PA1); also elsewhere on the board

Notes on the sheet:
SERIAL BUS
(6-PIN FEMALE DIN)
(24-PIN MALE EDGE)
USER PORT
RP3 3.3K
KEYBOARD
(20-PIN MALE)
(MALE DB9)
CONTROL PORT2
CONTROL PORT1
25V
2.7V
RP4 3.3K
7.5V
(6-PIN MALE EDGE)
CASSETTE
LED CONNECTOR
100V
POWER INPUT
(7PIN MALE DIN)
16V
50V
( 14.31818 MHz - NTSC ) ( 17.734472 MHz - PAL )
To Cartridge Expansion

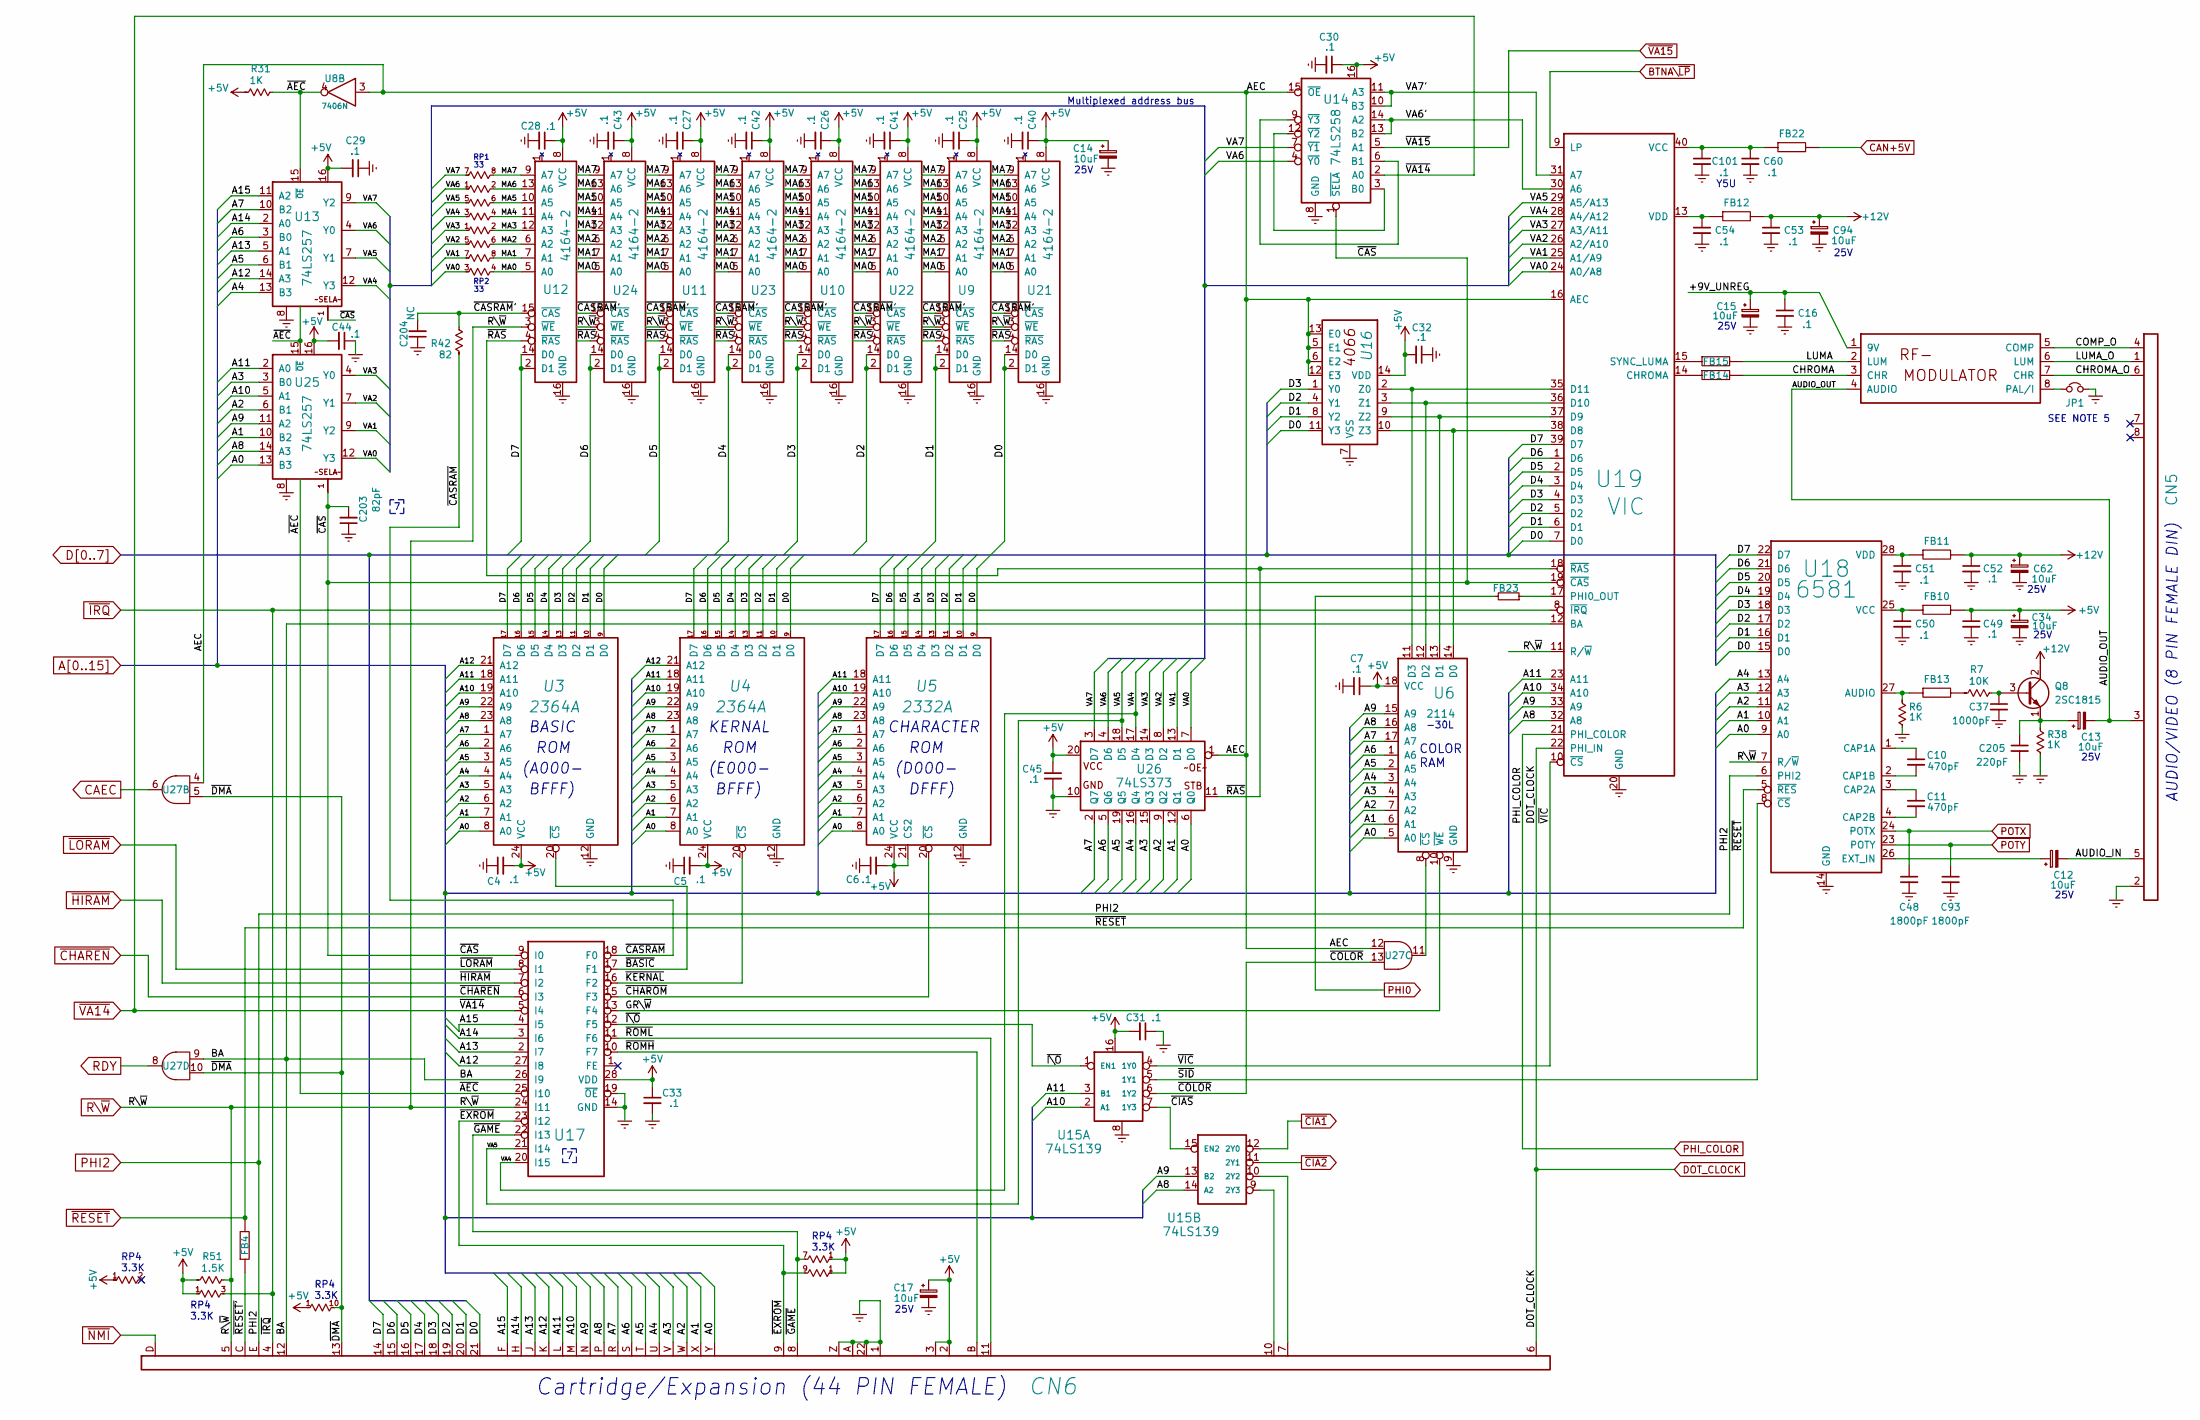
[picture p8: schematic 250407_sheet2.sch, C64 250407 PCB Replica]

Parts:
C4, C5, C6, C7, C16, C25, C26, C27, C28, C29, C30, C31, C32, C33, C40, C41, C42, C43, C44, C45, C49, C50, C51, C52, C53, C54, C60, C101: .1; CAP_P5.08mm
C10, C11: 470pF; CAP_P5.08mm
C12, C13, C14, C15, C17, C34, C62, C94: 10uF; CAP_ELYT_RADIAL_P5.08mm_SMALL_RING
C37: 1000pF; CAP_P5.08mm
C48, C93: 1800pF; CAP_P5.08mm
C203: 82pF; CAPACITOR_RADIAL_P13.97_L9.9_D3.6
C204: NC; CAP_P5.08mm
C205: 220pF; CAP_P5.08mm
CN5: AV_CONN; AV_CON_DIN8
CN6: EXPANSION_PORT
FB4, FB10, FB11, FB12, FB13, FB14, FB15, FB22, FB23: FERRITE_BEAD; FERRITE_BEAD_TH_P12.7mm
JP1: Jumper_NC_Small; SolderJumper-2_P1.3mm_Bridged_RoundedPad1.0x1.5mm
M1: MODULATOR_LONGBOARD; MODULATOR_PORT_LONGBOARD
Q8: 2SC1815; Q_NPN_ECB
R6, R31, R38: 1K; RESISTOR
R7: 10K; RESISTOR
R42: 82; RESISTOR
R51: 1.5K; RESISTOR
RP1, RP2: 33R isolated; RP_ARRAY_7WAY
RP4: 3K3 Bussed; RP_ARRAY_9WAY
U3, U4: 2364A; DIP24
U5: 2332A; DIP24
U6: 2114; DIP18
U8: 7406N; DIP14
U9, U10, U11, U12, U21, U22, U23, U24: 4164-2; DIP16
U13, U25: 74LS257; DIP16
U14: 74LS258; DIP16
U15: 74LS139; DIP16
U16: 4066_U28; DIP14
U17: PLA_U17; DIP28
U18: 6581; DIP28
U19: VIC; DIP40
U26: 74LS373; DIP20
U27: 7408_U27; DIP14

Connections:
+5V: C4.2, C5.2, C6.2, C7.1, C14.1, C17.1, C25.1, C26.1, C27.1, C28.1, C29.2, C30.1, C31.2, C32.2, C33.1, C34.1, C40.1, C41.1, C42.1, C43.1, C44.2, C45.1, C49.1, CN6.2, CN6.3, FB10.2, R31.2, R51.2, RP4.1, U3.24 (VCC), U4.24 (VCC), U5.21 (CS2), U5.24 (VCC), U6.18 (VCC), U9.8 (VCC), U10.8 (VCC), U11.8 (VCC), U12.8 (VCC), U13.16, U14.16, U15.16, U16.14 (VDD), U17.28 (VDD), U21.8 (VCC), U22.8 (VCC), U23.8 (VCC), U24.8 (VCC), U25.16, U26.20; also elsewhere on the board
+9V_UNREG: C15.1, C16.1, M1.1 (9V); also elsewhere on the board
+12V: C52.1, C53.1, C62.1, C94.1, FB11.2, FB12.2, Q8.2 (C); also elsewhere on the board
/250407_sheet2/AEC: U8.3, U14.15 (~OE~), U16.5 (E1), U16.6 (E2), U16.12 (E3), U16.13 (E0), U19.16 (AEC), U26.1, U27.4, U27.12
/250407_sheet2/AUDIO_IN: C12.2, CN5.5
/250407_sheet2/AUDIO_OUT: C13.2, CN5.3, M1.4 (AUDIO)
/250407_sheet2/BA: CN6.12, U17.26 (I9), U19.12 (BA), U27.9
/250407_sheet2/CHROMA: FB14.2, M1.3 (CHR)
/250407_sheet2/CHROMA_O: CN5.6, M1.7 (CHR)
/250407_sheet2/COMP_O: CN5.4, M1.5 (COMP)
/250407_sheet2/GR\~W~: U6.10 (~WE~), U17.13 (F4)
/250407_sheet2/LUMA: FB15.2, M1.2 (LUM)
/250407_sheet2/LUMA_O: CN5.1, M1.6 (LUM)
/250407_sheet2/MA0: RP2.4, U9.5 (A0), U10.5 (A0), U11.5 (A0), U12.5 (A0), U21.5 (A0), U22.5 (A0), U23.5 (A0), U24.5 (A0)
/250407_sheet2/MA1: RP2.8, U9.7 (A1), U10.7 (A1), U11.7 (A1), U12.7 (A1), U21.7 (A1), U22.7 (A1), U23.7 (A1), U24.7 (A1)
/250407_sheet2/MA2: RP2.6, U9.6 (A2), U10.6 (A2), U11.6 (A2), U12.6 (A2), U21.6 (A2), U22.6 (A2), U23.6 (A2), U24.6 (A2)
/250407_sheet2/MA3: RP2.2, U9.12 (A3), U10.12 (A3), U11.12 (A3), U12.12 (A3), U21.12 (A3), U22.12 (A3), U23.12 (A3), U24.12 (A3)
/250407_sheet2/MA4: RP1.4, U9.11 (A4), U10.11 (A4), U11.11 (A4), U12.11 (A4), U21.11 (A4), U22.11 (A4), U23.11 (A4), U24.11 (A4)
/250407_sheet2/MA5: RP1.6, U9.10 (A5), U10.10 (A5), U11.10 (A5), U12.10 (A5), U21.10 (A5), U22.10 (A5), U23.10 (A5), U24.10 (A5)
/250407_sheet2/MA6: RP1.2, U9.13 (A6), U10.13 (A6), U11.13 (A6), U12.13 (A6), U21.13 (A6), U22.13 (A6), U23.13 (A6), U24.13 (A6)
/250407_sheet2/MA7: RP1.8, U9.9 (A7), U10.9 (A7), U11.9 (A7), U12.9 (A7), U21.9 (A7), U22.9 (A7), U23.9 (A7), U24.9 (A7)
/250407_sheet2/VA0: RP2.3, U19.24 (A0/A8), U25.12 (Y3), U26.7 (D0)
/250407_sheet2/VA1: RP2.7, U19.25 (A1/A9), U25.9 (Y2), U26.13 (D1)
/250407_sheet2/VA2: RP2.5, U19.26 (A2/A10), U25.7 (Y1), U26.8 (D2)
/250407_sheet2/VA3: RP2.1, U19.27 (A3/A11), U25.4 (Y0), U26.14 (D3)
/250407_sheet2/VA4: RP1.3, U13.12 (Y3), U17.20 (I15), U19.28 (A4/A12), U26.17 (D4)
/250407_sheet2/VA5: RP1.5, U13.7 (Y1), U17.21 (I14), U19.29 (A5/A13), U26.18 (D5)
/250407_sheet2/VA6: RP1.1, U13.4 (Y0), U14.4 (~Y0~), U26.4 (D6)
/250407_sheet2/VA6': U14.13 (B2), U14.14 (A2), U19.30 (A6)
/250407_sheet2/VA7: RP1.7, U13.9 (Y2), U14.7 (~Y1~), U26.3 (D7)
/250407_sheet2/VA7': U14.10 (B3), U14.11 (A3), U19.31 (A7)
/250407_sheet2/~AEC~: R31.1, U8.4, U13.15 (~OE~), U17.25 (I10), U25.15 (~OE~)
/250407_sheet2/~BASIC~: U3.20 (~CS~), U17.17 (F1)
/250407_sheet2/~CASRAM~: R42.2, U17.18 (F0)
/250407_sheet2/~CASRAM~': C204.2, R42.1, U9.15 (~CAS~), U10.15 (~CAS~), U11.15 (~CAS~), U12.15 (~CAS~), U21.15 (~CAS~), U22.15 (~CAS~), U23.15 (~CAS~), U24.15 (~CAS~)
/250407_sheet2/~CAS~: C203.2, U13.1 (~SELA~), U14.1 (~SELA~), U17.9 (I0), U19.19 (~CAS~), U25.1 (~SELA~)
/250407_sheet2/~CHAROM~: U5.20 (~CS~), U17.15 (F3)
/250407_sheet2/~CIAS~: U15.7 (1Y3), U15.15 (EN2)
/250407_sheet2/~COLOR~: U15.6 (1Y2), U27.13
/250407_sheet2/~DMA~: CN6.13, RP4.10, U27.5, U27.10
/250407_sheet2/~EXROM~: CN6.9, RP4.9, U17.23 (I12)
/250407_sheet2/~GAME~: CN6.8, RP4.7, U17.22 (I13)
/250407_sheet2/~I\O~: U15.1 (EN1), U17.12 (F5)
/250407_sheet2/~KERNAL: U4.20 (~CS~), U17.16 (F2)
/250407_sheet2/~RAS~: U9.4 (~RAS~), U10.4 (~RAS~), U11.4 (~RAS~), U12.4 (~RAS~), U19.18 (~RAS~), U21.4 (~RAS~), U22.4 (~RAS~), U23.4 (~RAS~), U24.4 (~RAS~), U26.11
/250407_sheet2/~RESET'~: CN6.C, FB4.1
/250407_sheet2/~ROMH~: CN6.B, U17.10 (F7)
/250407_sheet2/~ROML~: CN6.11, U17.11 (F6)
/250407_sheet2/~SID~: U15.5 (1Y1), U18.8 (~CS~)
/250407_sheet2/~VIC~: U15.4 (1Y0), U19.10 (~CS~)
A0: CN6.Y, U3.8 (A0), U4.8 (A0), U5.8 (A0), U6.5 (A0), U18.9 (A0), U25.13 (B3), U26.6 (Q0); also elsewhere on the board
A1: CN6.X, U3.7 (A1), U4.7 (A1), U5.7 (A1), U6.6 (A1), U18.10 (A1), U25.10 (B2), U26.12 (Q1); also elsewhere on the board
A2: CN6.W, U3.6 (A2), U4.6 (A2), U5.6 (A2), U6.7 (A2), U18.11 (A2), U25.6 (B1), U26.9 (Q2); also elsewhere on the board
A3: CN6.V, U3.5 (A3), U4.5 (A3), U5.5 (A3), U6.4 (A3), U18.12 (A3), U25.3 (B0), U26.15 (Q3); also elsewhere on the board
A4: CN6.U, U3.4 (A4), U4.4 (A4), U5.4 (A4), U6.3 (A4), U13.13 (B3), U18.13 (A4), U26.16 (Q4); also elsewhere on the board
A5: CN6.T, U3.3 (A5), U4.3 (A5), U5.3 (A5), U6.2 (A5), U13.6 (B1), U26.19 (Q5); also elsewhere on the board
A6: CN6.S, U3.2 (A6), U4.2 (A6), U5.2 (A6), U6.1 (A6), U13.3 (B0), U26.5 (Q6); also elsewhere on the board
A7: CN6.R, U3.1 (A7), U4.1 (A7), U5.1 (A7), U6.17 (A7), U13.10 (B2), U26.2 (Q7); also elsewhere on the board
A8: CN6.P, U3.23 (A8), U4.23 (A8), U5.23 (A8), U6.16 (A8), U15.14 (A2), U19.32 (A8), U25.14 (A3); also elsewhere on the board
A9: CN6.N, U3.22 (A9), U4.22 (A9), U5.22 (A9), U6.15 (A9), U15.13 (B2), U19.33 (A9), U25.11 (A2); also elsewhere on the board
A10: CN6.M, U3.19 (A10), U4.19 (A10), U5.19 (A10), U15.2 (A1), U19.34 (A10), U25.5 (A1); also elsewhere on the board
A11: CN6.L, U3.18 (A11), U4.18 (A11), U5.18 (A11), U15.3 (B1), U19.23 (A11), U25.2 (A0); also elsewhere on the board
A12: CN6.K, U3.21 (A12), U4.21 (A12), U13.14 (A3), U17.27 (I8); also elsewhere on the board
A13: CN6.J, U13.5 (A1), U17.2 (I7); also elsewhere on the board
A14: CN6.H, U13.2 (A0), U17.3 (I6); also elsewhere on the board
A15: CN6.F, U13.11 (A2), U17.4 (I5); also elsewhere on the board
BTNA\~LP~: U19.9 (LP); also elsewhere on the board
CAEC: U27.6; also elsewhere on the board
CAN+5V: FB22.2; also elsewhere on the board
D0: CN6.21, U3.9 (D0), U4.9 (D0), U5.9 (D0), U16.11 (Y3), U18.15 (D0), U19.7 (D0), U21.2 (D1), U21.14 (D0); also elsewhere on the board
D1: CN6.20, U3.10 (D1), U4.10 (D1), U5.10 (D1), U9.2 (D1), U9.14 (D0), U16.8 (Y2), U18.16 (D1), U19.6 (D1); also elsewhere on the board
D2: CN6.19, U3.11 (D2), U4.11 (D2), U5.11 (D2), U16.4 (Y1), U18.17 (D2), U19.5 (D2), U22.2 (D1), U22.14 (D0); also elsewhere on the board
D3: CN6.18, U3.13 (D3), U4.13 (D3), U5.13 (D3), U10.2 (D1), U10.14 (D0), U16.1 (Y0), U18.18 (D3), U19.4 (D3); also elsewhere on the board
D4: CN6.17, U3.14 (D4), U4.14 (D4), U5.14 (D4), U18.19 (D4), U19.3 (D4), U23.2 (D1), U23.14 (D0); also elsewhere on the board
D5: CN6.16, U3.15 (D5), U4.15 (D5), U5.15 (D5), U11.2 (D1), U11.14 (D0), U18.20 (D5), U19.2 (D5); also elsewhere on the board
D6: CN6.15, U3.16 (D6), U4.16 (D6), U5.16 (D6), U18.21 (D6), U19.1 (D6), U24.2 (D1), U24.14 (D0); also elsewhere on the board
D7: CN6.14, U3.17 (D7), U4.17 (D7), U5.17 (D7), U12.2 (D1), U12.14 (D0), U18.22 (D7), U19.39 (D7); also elsewhere on the board
DOT_CLOCK: CN6.6, U19.22 (PHI_IN); also elsewhere on the board
Earth: C4.1, C5.1, C6.1, C7.2, C14.2, C15.2, C16.2, C17.2, C25.2, C26.2, C27.2, C28.2, C29.1, C30.2, C31.1, C32.1, C33.2, C34.2, C37.2, C40.2, C41.2, C42.2, C43.2, C44.1, C45.2, C48.2, C49.2, C50.2, C51.2, C52.2, C53.2, C54.2, C60.2, C62.2, C93.2, C94.2, C101.2, C203.1, C204.1, C205.2, CN5.2, CN6.1, CN6.22, CN6.A, CN6.Z, JP1.2, R6.1, R38.1, U3.12 (GND), U4.12 (GND), U5.12 (GND), U6.9 (GND), U9.16 (GND), U10.16 (GND), U11.16 (GND), U12.16 (GND), U13.8, U14.8 (GND), U15.8, U16.7 (VSS), U17.14 (GND), U17.19 (~OE~), U18.14 (GND), U19.20 (GND), U21.16 (GND), U22.16 (GND), U23.16 (GND), U24.16 (GND), U25.8, U26.10; also elsewhere on the board
unnamed: C10.1, U18.1 (CAP1A)
unnamed: C10.2, U18.2 (CAP1B)
unnamed: C11.1, U18.3 (CAP2A)
unnamed: C11.2, U18.4 (CAP2B)
unnamed: C12.1, U18.26 (EXT_IN)
unnamed: C13.1, C205.1, Q8.1 (E), R38.2
unnamed: C37.1, Q8.3 (B), R7.1
unnamed: C50.1, FB10.1, U18.25 (VCC)
unnamed: C51.1, FB11.1, U18.28 (VDD)
unnamed: C54.1, FB12.1, U19.13 (VDD)
unnamed: C60.1, C101.1, FB22.1, U19.40 (VCC)
unnamed: CN6.7, U15.10 (2Y2)
unnamed: CN6.10, U15.9 (2Y3)
unnamed: FB13.1, R6.2, U18.27 (AUDIO)
unnamed: FB13.2, R7.2
unnamed: FB14.1, U19.14 (CHROMA)
unnamed: FB15.1, U19.15 (SYNC_LUMA)
unnamed: FB23.1, U19.17 (PHI0_OUT)
unnamed: JP1.1, M1.8 (PAL/I)
unnamed: U14.6 (B1), U14.9 (~Y3~)
unnamed: U14.3 (B0), U14.12 (~Y2~)
unnamed: U6.11 (D3), U16.2 (Z0), U19.35 (D11)
unnamed: U6.12 (D2), U16.3 (Z1), U19.36 (D10)
unnamed: U6.13 (D1), U16.9 (Z2), U19.37 (D9)
unnamed: U6.14 (D0), U16.10 (Z3), U19.38 (D8)
unnamed: U6.8 (~CS~), U27.11
PHI0: FB23.2; also elsewhere on the board
PHI2: CN6.E, U18.6 (PHI2); also elsewhere on the board
PHI_COLOR: U19.21 (PHI_COLOR); also elsewhere on the board
POTX: C48.1, U18.24 (POTX); also elsewhere on the board
POTY: C93.1, U18.23 (POTY); also elsewhere on the board
RDY: U27.8; also elsewhere on the board
R\~W~: CN6.5, R51.1, U9.3 (~WE~), U10.3 (~WE~), U11.3 (~WE~), U12.3 (~WE~), U17.24 (I11), U18.7 (R/~W~), U19.11 (R/~W~), U21.3 (~WE~), U22.3 (~WE~), U23.3 (~WE~), U24.3 (~WE~); also elsewhere on the board
~CHAREN~: U17.6 (I3); also elsewhere on the board
~CIA1~: U15.12 (2Y0); also elsewhere on the board
~CIA2~: U15.11 (2Y1); also elsewhere on the board
~HIRAM~: U17.7 (I2); also elsewhere on the board
~IRQ~: CN6.4, RP4.3, U19.8 (~IRQ~); also elsewhere on the board
~LORAM~: U17.8 (I1); also elsewhere on the board
~NMI~: CN6.D; also elsewhere on the board
~RESET~: FB4.2, U18.5 (~RES~); also elsewhere on the board
~VA14~: U14.2 (A0), U17.5 (I4); also elsewhere on the board
~VA15~: U14.5 (A1); also elsewhere on the board

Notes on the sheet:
RP1
RP2
BASIC
ROM
(A000-
BFFF)
KERNAL
(E000-
CHARACTER
(D000-
DFFF)
RP4 3.3K
Cartridge/Expansion (44 PIN FEMALE)
Multiplexed address bus
25V
-30L
COLOR RAM
AUDIO/VIDEO (8 PIN FEMALE DIN)
Y5U
SEE NOTE 5

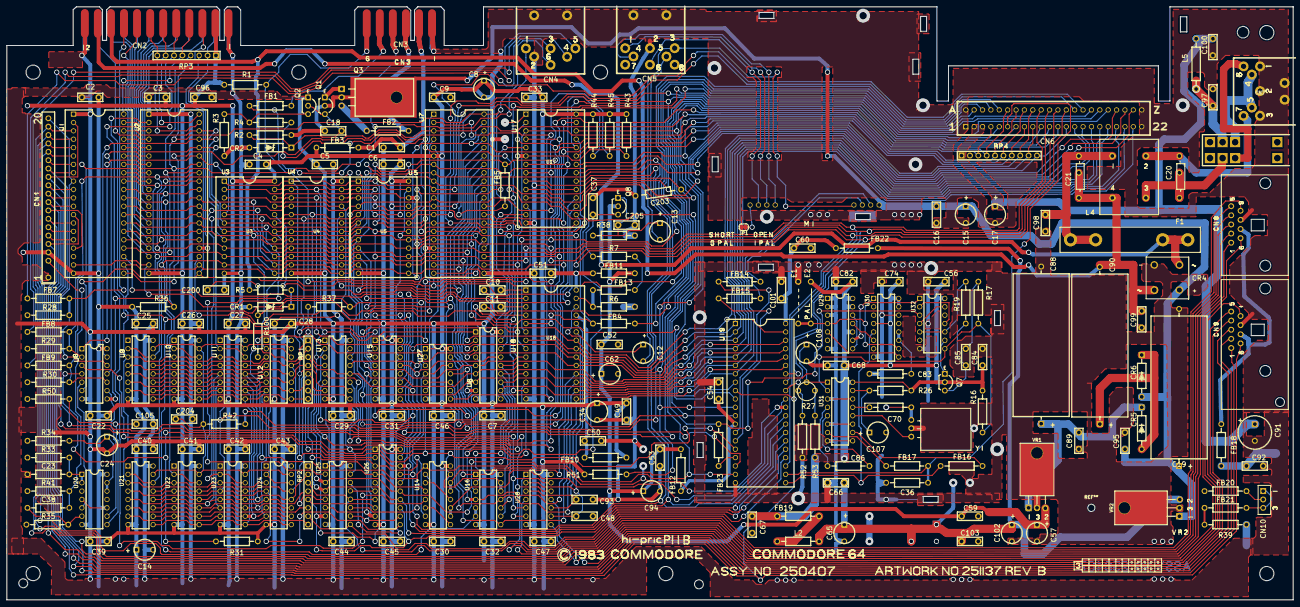
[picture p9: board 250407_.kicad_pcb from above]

Board: 2 copper layers, 390.0 x 179.8 mm, 215 parts (0 on the bottom side), 227 nets.

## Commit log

2021-04-20 the interactive bom added
2021-04-20 Added interactive bom link in readme.
2021-06-19 Rev 1.1 release
    [250407_-B_Cu.gbr, 250407_-B_Mask.gbr, 250407_-B_SilkS.gbr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]
2021-08-24 TP29B #2
    [250407_.kicad_pcb, 250407_.sch, 250407_bom.csv]
2022-07-31 Fixed pin names in 4164 symbols
2022-07-31 Correct Input/Output pin type for 74LS258
2022-07-31 Correct pin types for many ICs to reduce the numebr or ERC errors and warnings
2022-07-31 Additional changes to the pin properties. Now only 11 warning in the ERC check.
2022-08-10 Fix north PCB edge
    [250407_.kicad_pcb]
2022-08-18 Update schematics version and readme
    [250407_.sch, 250407_sheet2.sch]
2022-08-20 updated second schematics Revision and comment
    [250407_sheet2.sch]

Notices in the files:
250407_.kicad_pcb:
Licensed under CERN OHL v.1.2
